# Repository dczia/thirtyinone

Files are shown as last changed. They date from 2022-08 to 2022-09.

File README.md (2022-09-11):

# thirtyinone
defcon 30 30-in-One badge

This Is The Video You Are Looking For (https://www.youtube.com/watch?v=AAD9OO9EeQw "DCZia 30 in 1 Electronic Project Kit Badge Overview")

For those who don't like videos, here is a reasonable ordering of adding components:
* Pins (broken out all at once or a few at a time
* OLED Screen - top left, for pins
* Switches (next to battery, under keycaps hope)
* RGB LED - to the left of the other LEDS
* Speaker bottom right, on top of the spot of tape.  Polarity does not matter
* Battery case (big blank spot, bottom left)
* Key base (top right-should be obvious)
* Transformer (note THIS one is directional-the P side should line up with the P on the board)
* Potentiometer (next to the key base)
* Key Cap

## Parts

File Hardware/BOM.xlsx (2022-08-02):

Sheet: Sheet1
Ref Des | Description | Mfg Part # | Package | Supplier | Supplier Part # | QTY per badge
Transistors
Q101,102 | Transistor NPN 3904 | CMPT3904E TR PBFREE | SOT232 | Mouser | 610-CMPT3904E | 2
Q103 | Transistor PNP 3906 | CMPT3906G TR PBFREE | SOT232 | Mouser | 610-CMPT3906G | 1
Caps
C1 | 2.2uF | 885012107001 | 0805 | Mouser | 710-885012107001 | 1
C2 | 470pF | C0805Y471J9RACTU | 0805 | Mouser | 80-C0805Y471J9R | 1
C3,4,C114 | 10uF | CL10A106MQ8NNND | 0603 | Mouser | 187-CL10A106MQ8NNND | 3
C8 | 1uF | C0603C105K9PACTU | 0603 | Mouser | 80-C0603C105K9P | 1
C9,C10 | 47pF | 06036A470KAT2A | 0603 | Mouser | 581-06036A470KAT2A | 2
C111 | 470uF | 865080153012 |  | Mouser | 710-865080153012 | 1
C112 | 100uF | 865080142007 |  | Mouser | 710-865080142007 | 1
C113 | 22uF | CL21A226MQQNNNE | 0805 | Mouser | 187-CL21A226MQQNNNE | 1
C5-7,115,116 | 0.1uF | 06034C104KAT2A | 0603 | Mouser | 581-06034C104KAT2A | 5
C117 | 0.033uF | GRM1887U0J333JA01D | 0603 | Mouser | 81-GRM1887U0J333JA1D | 1
C118 | 0.01uF | 80-C0603C103K9R | 0603 | Mouser | C0603C103K9RACTU | 1
Diodes
D1,2,3 | Schottky diode single | SS0530_R1_00001 | SOD-123-2 | Mouser | 241-SS0530_R1_00001 | 3
D104 | RGB LED | CLX6F-FKC-CKNNQDGBB7A363 |  | Mouser | 941-CLX6FFKCCKNNQDGB | 1
D3,4 | Schottky diode dual | BAT54S-TP | SOT23 | Mouser | 833-BAT54S-TP | 2
D102,103 | LED Green | 150080GS75000 | 0805 | Mouser | 710-150080GS75000 | 2
Resistors
R1,2 | 27R | ERJ-3GEYJ270V | 0603 | Mouser | 667-ERJ-3GEYJ270V | 2
R103 | 100k | RK73B1JTTD104J | 0603 | Mouser | 660-RK73B1JTTD104J | 1
R104 | 10k | CR0603-JW-103ELF | 0603 | Mouser | 652-CR0603-JW-103ELF | 1
R105 | 5.6k | CR0603-JW-562ELF | 0603 | Mouser | 652-CR0603JW-562ELF | 1
R106 | 1k | ERJ-3GEYJ102V | 0603 | Mouser | 667-ERJ-3GEYJ102V | 1
R107 | 680R | CR0603-JW-681ELF | 0603 | Mouser | 652-CR0603JW-681ELF | 1
R108-110 | 100R | ERJ-3GEYJ101V | 0603 | Mouser | 667-ERJ-3GEYJ101V | 3
R111 | CdS Photo Cell | 161 |  | Mouser | 485-161 | 1
RV101 | 50k Potentiometer | RK09D113000D |  | Mouser | 688-RK09D113000D | 1
Chips
U2 | Microcontroller | ATSAMD21G15A-AU | TQFP-48 | Mouser | 556-ATSAMD21G15A-AU | 1
U1 | LDO vreg | MIC5219-3.6YM5-TR | SOT23 | Mouser | 998-MIC5219-3.6YM5TR | 1
Connectors
J1 | SWD | NO STUFF |  |  |  | 0
J2 | Tag Connect | NO STUFF |  |  |  | 0
J3 | OLED 4 pin header |  |  |  |  | 1
J4 | USB micro | USB3140-30-0170-1-C |  | Mouser | 640-USB31403001701C | 1
J5 | uC interface 14 pin
J105-158,168,169 | 2 pin socket |  |  |  |  | 56
J159-J167 | 3 pin socket |  |  |  |  | 9
J170-175 | 6 pin socket |  |  |  |  | 6
Socket strip | 175 sockets per badge |  | 40 pins | Amazon | https://www.amazon.com/Uxcell-a14081900ux0270-Single-Straight-Header/dp/B012ACSO4Y | 5
Misc
LS101 | Speaker | CMS-151135-078L100 |  | Mouser | 490-CMS151135078L100 | 1
SW1,103 | Switch SPDT | MHSS1104 |  | Mouser | 642-MHSS1104 | 2
SW2 | Push button bootload | PTS526 SK15 SMTR2 LFS |  | Mouser | 611-PTS526SK15SMR2L | 1
SW104 | Cherry MX |  |  |  |  | 1
BT1 | Battery box | 2479 |  | Mouser | 534-2479 | 1
T101 | Transformer | 42TL013-RC |  | Mouser | 42TL013-RC | 1

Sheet: Sheet2
 |  |  | Test? | Sch? | Resistors |  |  |  |  |  |  |  |  |  |  |  |  | Capacitors |  |  |  |  | LEDs |  | Transistor |  |  | Switch
 |  |  |  |  | 100R | 100R | 1K | 1K | 5K | 10K | 10K | 47K | 100k | 50K Pot | Photo | 100pF | 0.01uF | 0.02uF | 0.05uF | 0.1uF | 10uF | 100uF | Single | RGB | 2N3906 PNP | 2N5830 NPN | 2SC NPN | Button | SPST | Speaker | Transformer | Diode | NAND
1 | Light the LED |  |  | Y | x |  |  |  |  |  |  |  |  |  |  |  |  |  |  |  |  |  | x |  |  |  |  | x
2 | LEDs and Resistors |  |  | Y | x |  |  |  |  |  |  |  |  | x |  |  |  |  |  |  |  |  | x |  |  |  |  |  | x
3 | RGB Mixing |  |  | P | x | x |  |  |  |  |  |  |  | x |  |  |  |  |  |  |  |  |  | x |  |  |  |  | x
4 | Storage Tank | 35 in one - 2 |  | Y |  |  |  | x |  |  |  |  |  |  |  |  |  |  |  |  |  | x | x
5 | Diodes | 35 in one - 3 |  | y |  |  |  | x |  |  |  |  |  |  |  |  |  |  |  |  |  |  | x
6 | Resistors in Series/Parallel |  |  |  |  |  | x | x | x | x | x |  |  | x
7 | Temp Sensor | 75 in one - 11 | Y | y |  |  | x |  |  |  |  |  |  | x |  |  |  |  |  |  |  |  |  |  |  | x
8 | Metronome |  | Y | P |  |  |  |  |  | x |  |  |  | x |  |  |  |  |  |  | x |  |  |  | x | x |  |  |  | x
9 | Electronic cat | 150 in one - 8 | y | y |  | x |  |  |  | x |  |  |  | x |  |  | x |  | x |  | x | x |  |  | x |  |  | x | x | x | x
10 | Electronic motorcycle | 150 in one - 9 | y | y |  |  |  |  |  | x |  |  |  |  | x |  |  |  | x | x |  |  |  |  | x |  |  |  |  | x | x
11 | Patrol Car Siren | 150 in one - 11 | y | y |  |  |  |  |  | x |  |  |  |  |  | x | x |  |  |  |  |  |  |  | x |  |  | x
12 | Light Theremin | 150 in one - 16 | y | y |  |  | x |  |  |  |  |  |  |  | x |  |  | x |  | x |  |  |  |  | x |  |  | x |  | x | x
13 | Sunrise/Sunset | 35 in one - 7 | y | y |  |  |  | x |  |  |  |  | x |  |  |  |  |  |  |  |  | x | x |  |  | x
14 | Touch Circuit | 35 in one - 17 | y | y |  |  |  | x | x | x |  |  | x |  |  |  |  |  |  |  |  |  | x |  |  | x | x
15 | The Blinker | 35 in one - 23 | y | y |  |  |  | x | x | x |  |  | x |  |  |  |  |  |  |  | x | x | x |  |  | x | x
16 | Early bird | 150 in one - 91 | y | y |  |  |  |  |  |  |  | x |  | x | x |  | x |  |  | x |  | x |  |  | x |  |  | x |  | x | x
17 | Audio Osc | 150 in one - 144 | y | y | x |  |  |  |  | x | x |  |  | x |  |  |  |  |  | x |  |  |  |  | x | x |  | x |  | x
18 | Grandfather Clock | 500 in one - 41 or 150 in one - 15 | y | y | x |  |  |  |  |  |  |  | x |  |  |  |  | x |  |  |  | x |  |  | x |  |  |  |  | x | x
19 | Pulse Osc | 150 in one - 145 | y | y |  |  |  |  |  |  | x |  |  | x |  |  |  |  | x | x |  |  |  |  | x |  |  | x |  | x | x
20 | Light controlled switch | 150 in one - 72 | y | y |  |  | x | x |  |  |  |  |  | x | x |  |  |  |  |  |  |  | x |  | x
21 | AND with switches | 150 in one - 48 | y | y |  |  |  | x |  |  |  |  |  |  |  |  |  |  |  |  |  |  | x |  |  |  |  | x | x
22 | OR with switches | 150 in one - 49 | y | y |  |  |  | x |  |  |  |  |  |  |  |  |  |  |  |  |  |  | x |  |  |  |  | x | x
23 | NOR with switches | 150 in one - 51 | y | y |  |  |  |  |  |  | x |  |  |  |  |  |  |  |  |  |  |  | x |  | x |  |  | x | x
24 | Code Practice | 150 in one - 105
25 | Pulse Stretcher | 150 in one - 56
26 | RS flip flop | 150 in one - 57
27 | Turn off delay osc | 150 in one - 65
28 | Code RGB
29 | Code frequency counter
30 | Code ADC

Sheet: Sheet3
Part | Qty
Caps
100uF | 1 | p | x
10uF | 1 | p | x
0.05uF | 1 |  | x
0.1uF | 2 |  | x
22uF | 1 |  | x
0.01uF | 1 |  | x
470uF | 1 |  | x
LEDs
LED | 2 |  | x
RGB | 1 |  | x
Speaker | 1 |  | x
2N3904 NPN | 2 |  | x
2N3906 PNP | 1 |  | x
Resistors
100 | 3 |  | x
1k | 1 |  | x
10K | 1 |  | x
5.6K | 1 |  | x
100K | 1 |  | x
680 | 1 |  | x
50K pot | 1 |  | x
Push Switch | 1 |  | x
SPST | 1 |  | x
Transformer | 1 |  | x
CdS cell | 1 |  | x
Total | 28

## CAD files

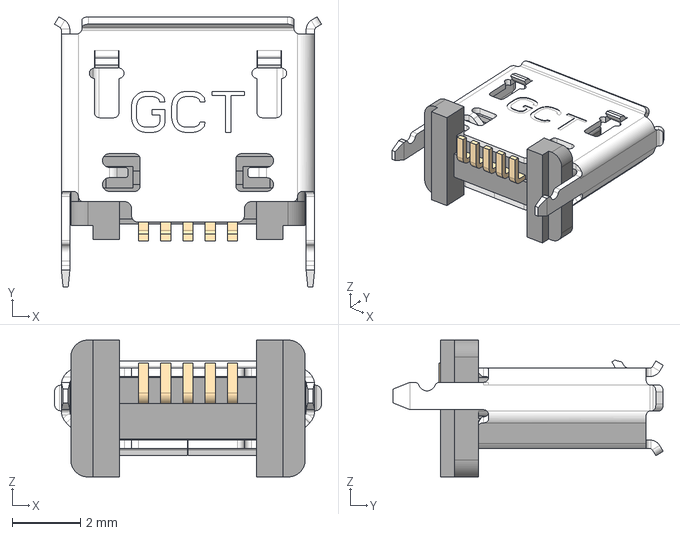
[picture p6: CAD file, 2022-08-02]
Hardware/badge/3d/USB3140-30-0140-1-C.stp
7.80 x 7.90 x 4.00 mm

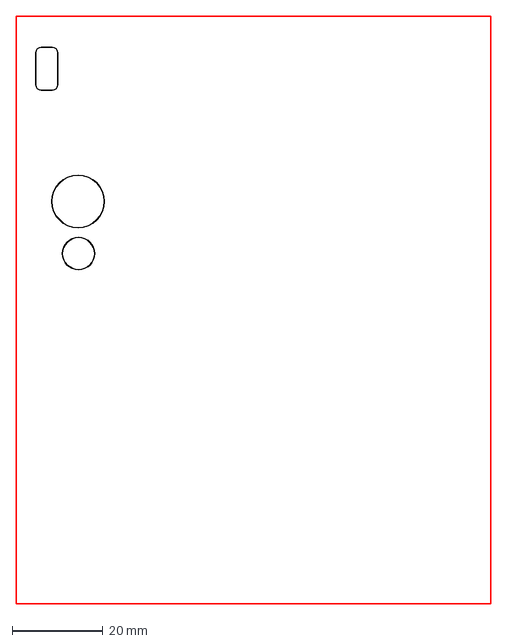
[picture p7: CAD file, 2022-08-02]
Hardware/badge/images/solder-helper.dxf
104.7 x 129.7 mm

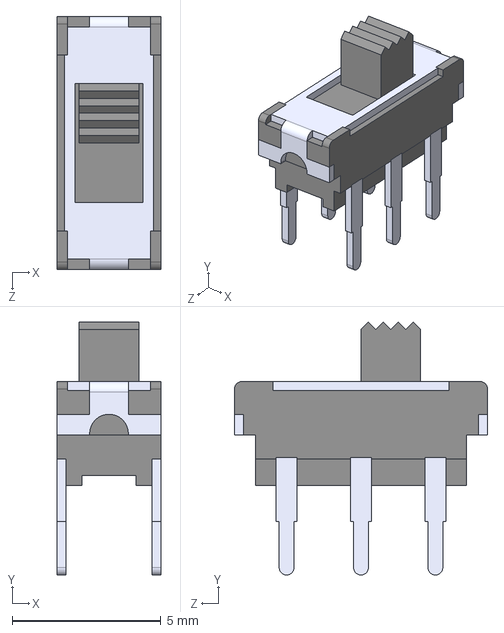
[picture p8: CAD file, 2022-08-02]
Hardware/badge/3d/MHSS1104--3DModel-STEP-56544.STEP
3.50 x 8.50 x 8.50 mm

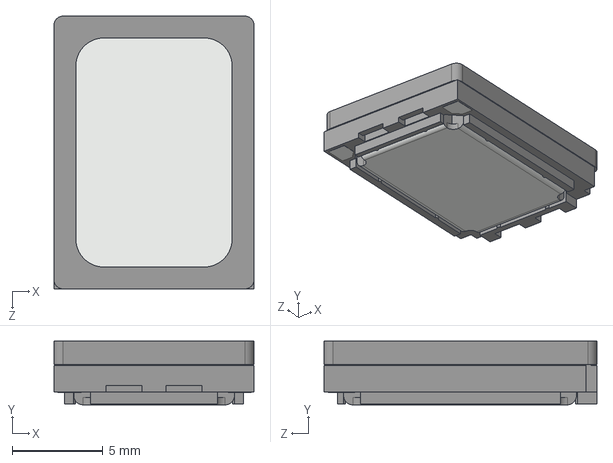
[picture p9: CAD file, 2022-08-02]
Hardware/badge/3d/CUI_DEVICES_CMS-151135-078SP-67.step
11.0 x 3.50 x 15.0 mm

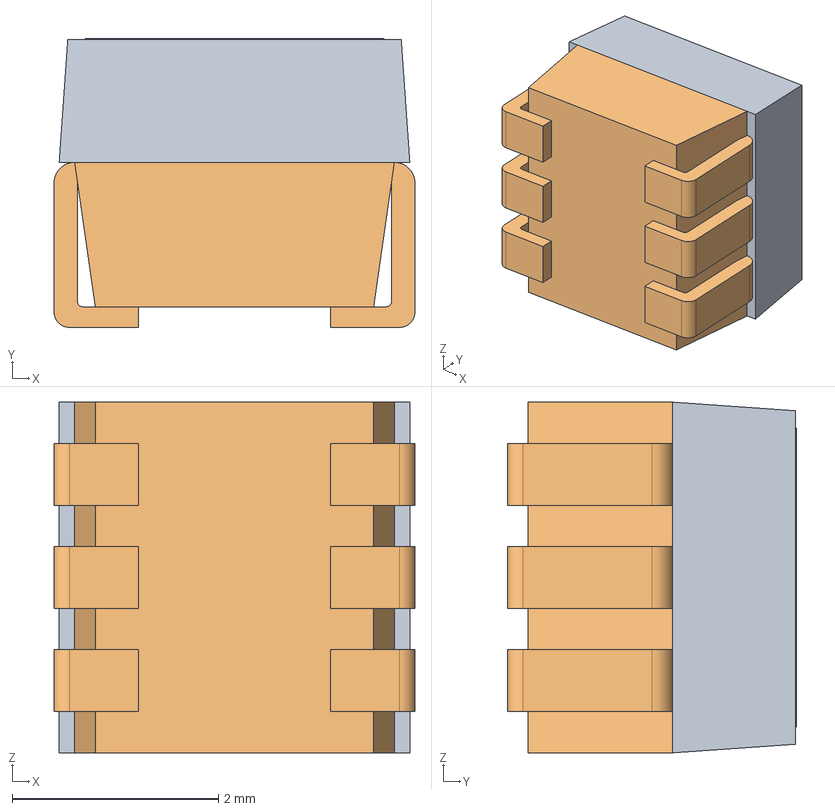
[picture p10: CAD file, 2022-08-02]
Hardware/badge/3d/Cree_PLCC6.stp
3.50 x 2.80 x 3.40 mm
CORPS-DPLACER_COPI0001_1
CORPS-DPLACER_COPI0002_1

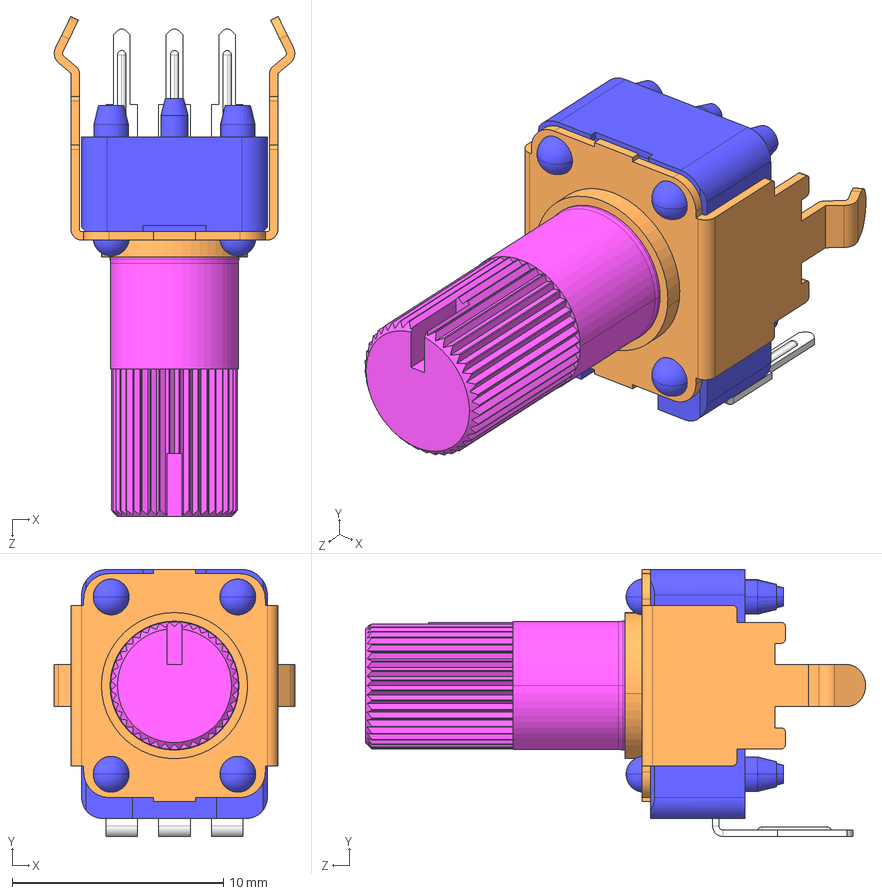
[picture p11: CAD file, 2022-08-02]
Hardware/badge/3d/RK09K1130D62.STEP
11.4 x 12.7 x 23.7 mm

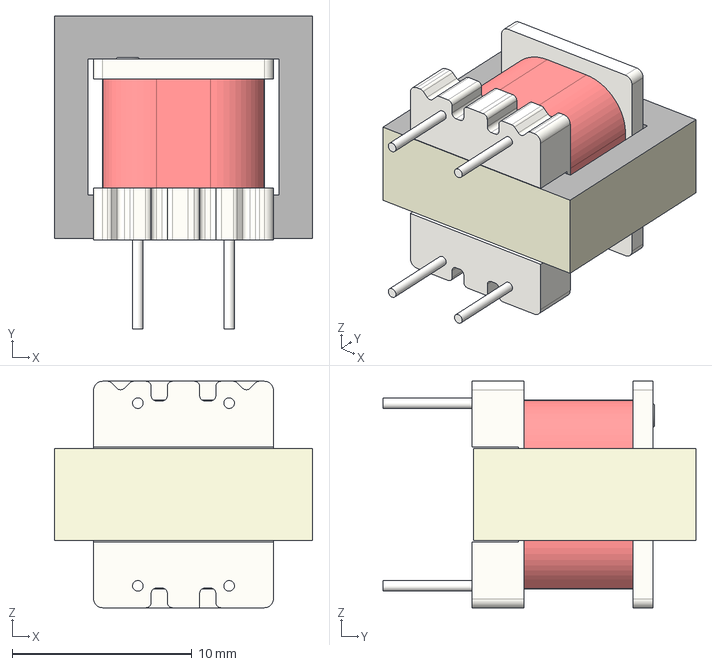
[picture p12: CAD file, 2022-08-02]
Hardware/badge/3d/EE14 Red Audio Transformer v3.step
14.3 x 17.4 x 12.6 mm

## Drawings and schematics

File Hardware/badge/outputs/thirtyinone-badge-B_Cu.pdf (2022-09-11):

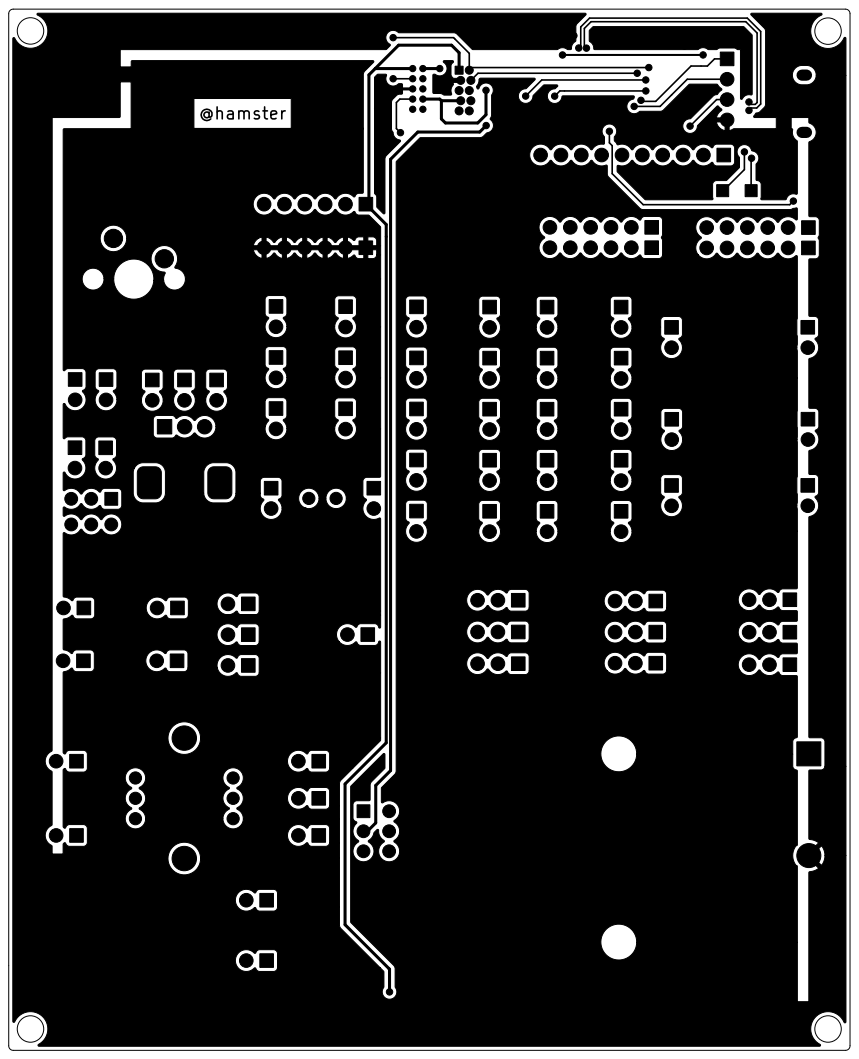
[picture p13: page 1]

File: thirtyinone-badge.kicad_pcb Sheet: DCZia

Id: 1/1 Title: 30-in-One

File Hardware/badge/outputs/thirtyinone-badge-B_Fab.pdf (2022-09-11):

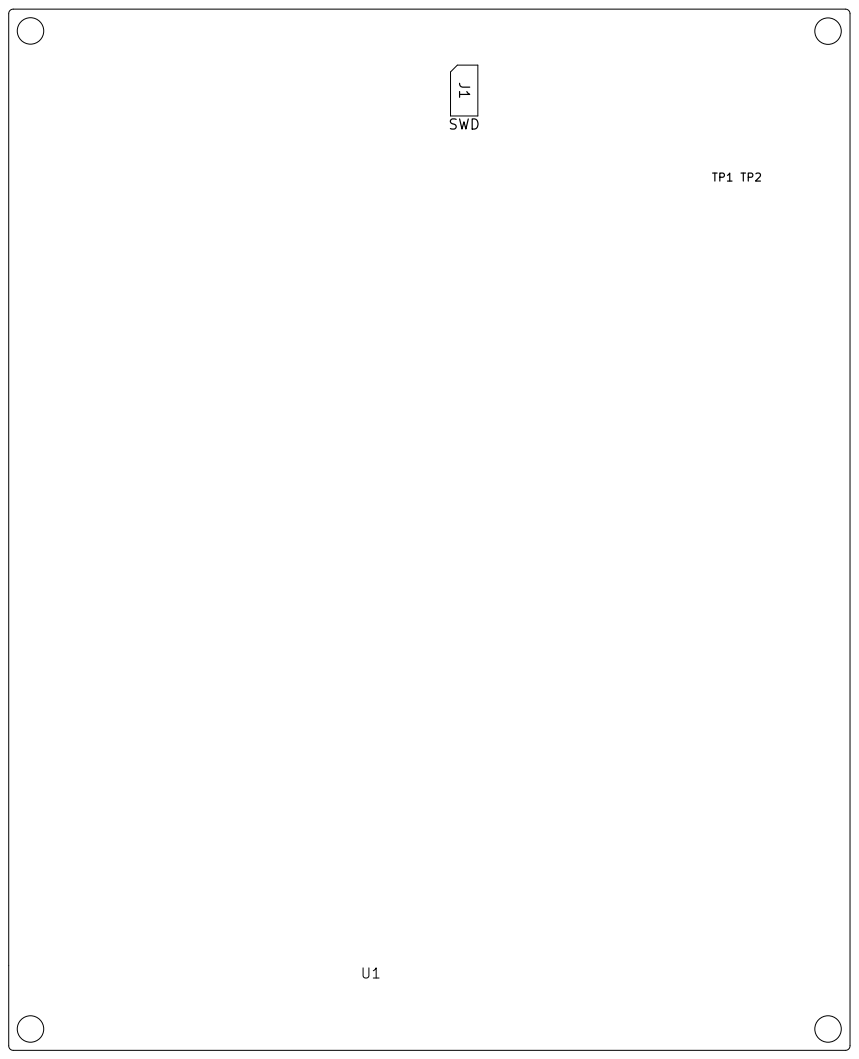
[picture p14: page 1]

File: thirtyinone-badge.kicad_pcb Sheet: DCZia

Id: 1/1 Title: 30-in-One

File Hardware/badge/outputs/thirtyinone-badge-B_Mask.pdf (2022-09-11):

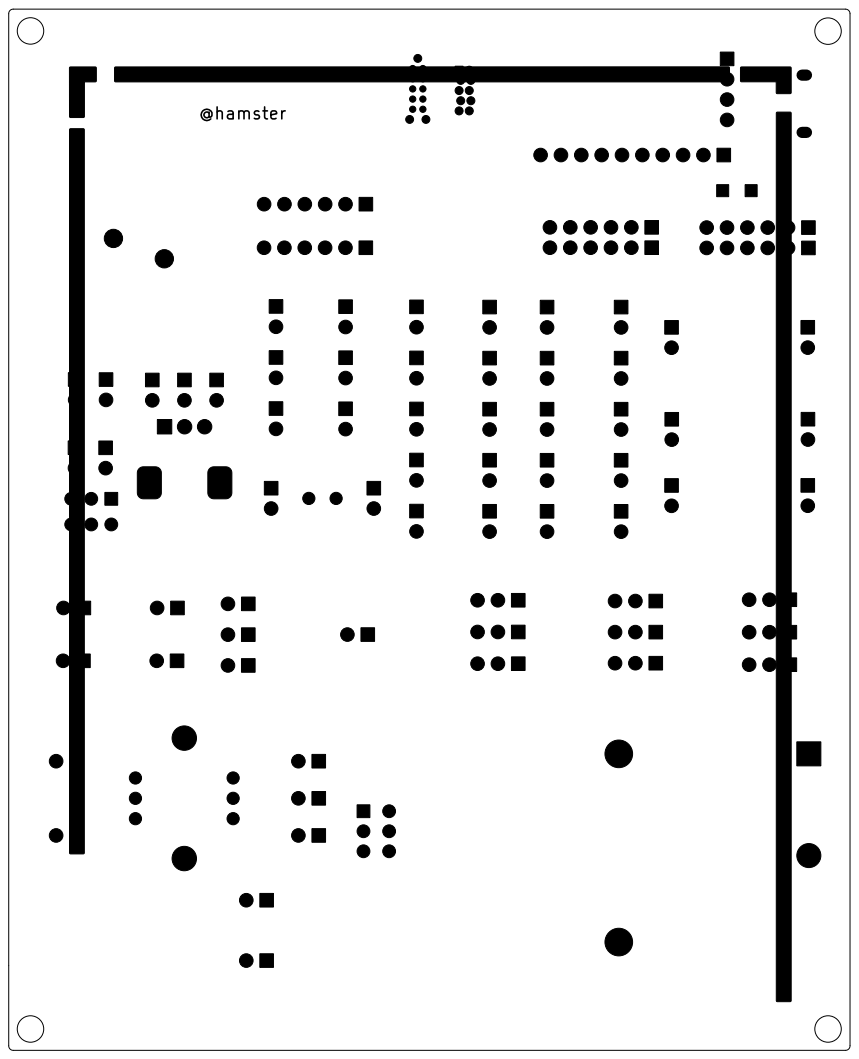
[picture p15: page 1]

File: thirtyinone-badge.kicad_pcb Sheet: DCZia

Id: 1/1 Title: 30-in-One

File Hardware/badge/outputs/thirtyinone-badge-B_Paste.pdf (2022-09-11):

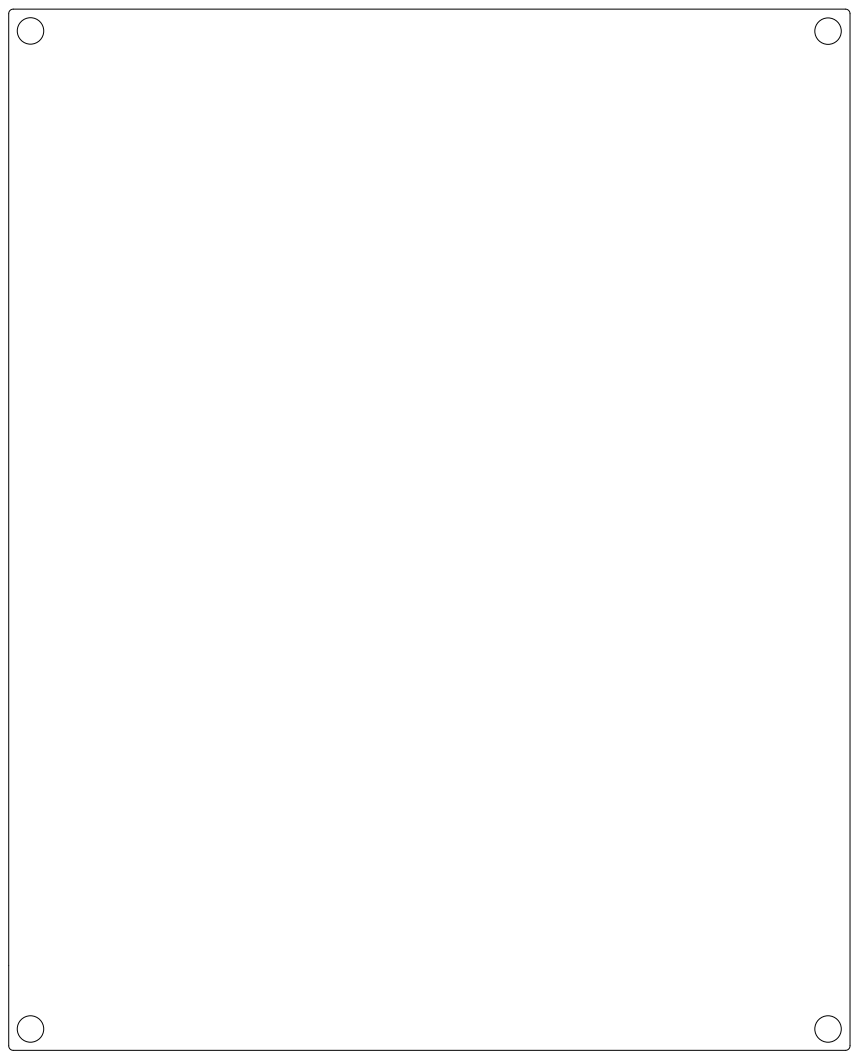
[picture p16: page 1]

defcon 30
File: thirtyinone-badge.kicad_pcb Sheet: DCZia

Id: 1/1 Title: 30-in-One

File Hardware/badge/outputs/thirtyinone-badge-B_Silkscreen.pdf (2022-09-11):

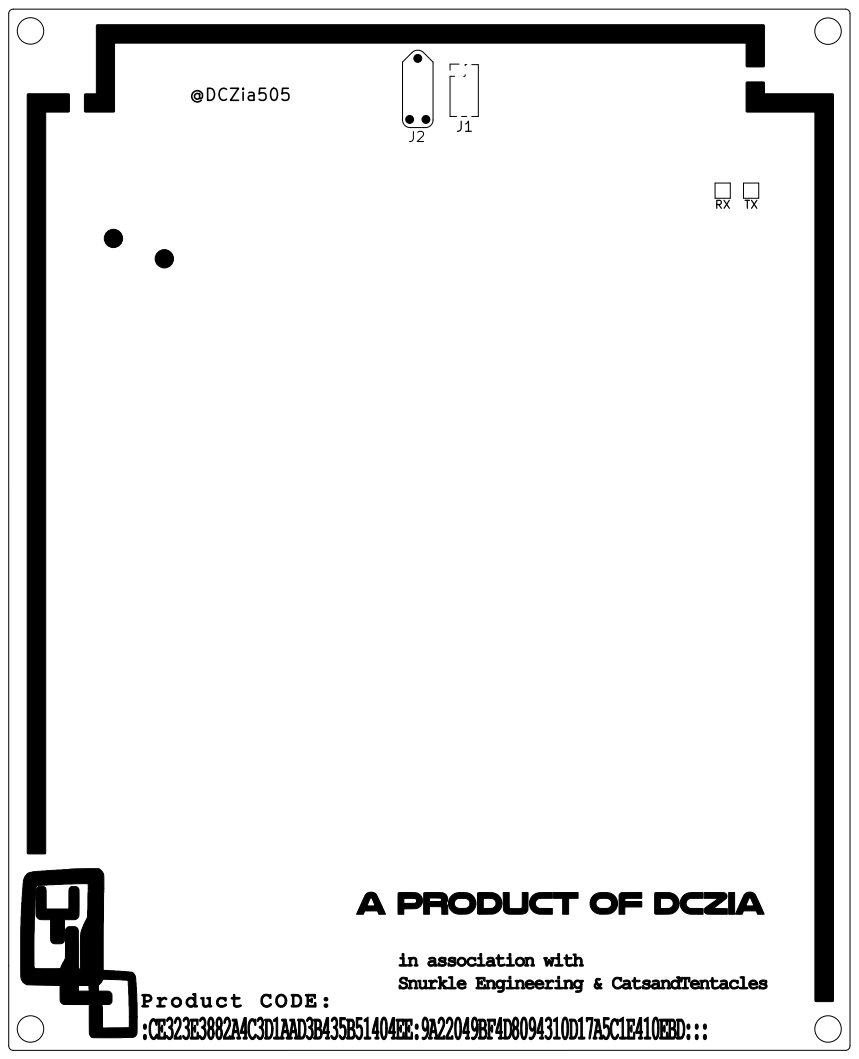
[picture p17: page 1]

File: thirtyinone-badge.kicad_pcb Sheet: DCZia

Id: 1/1 Title: 30-in-One

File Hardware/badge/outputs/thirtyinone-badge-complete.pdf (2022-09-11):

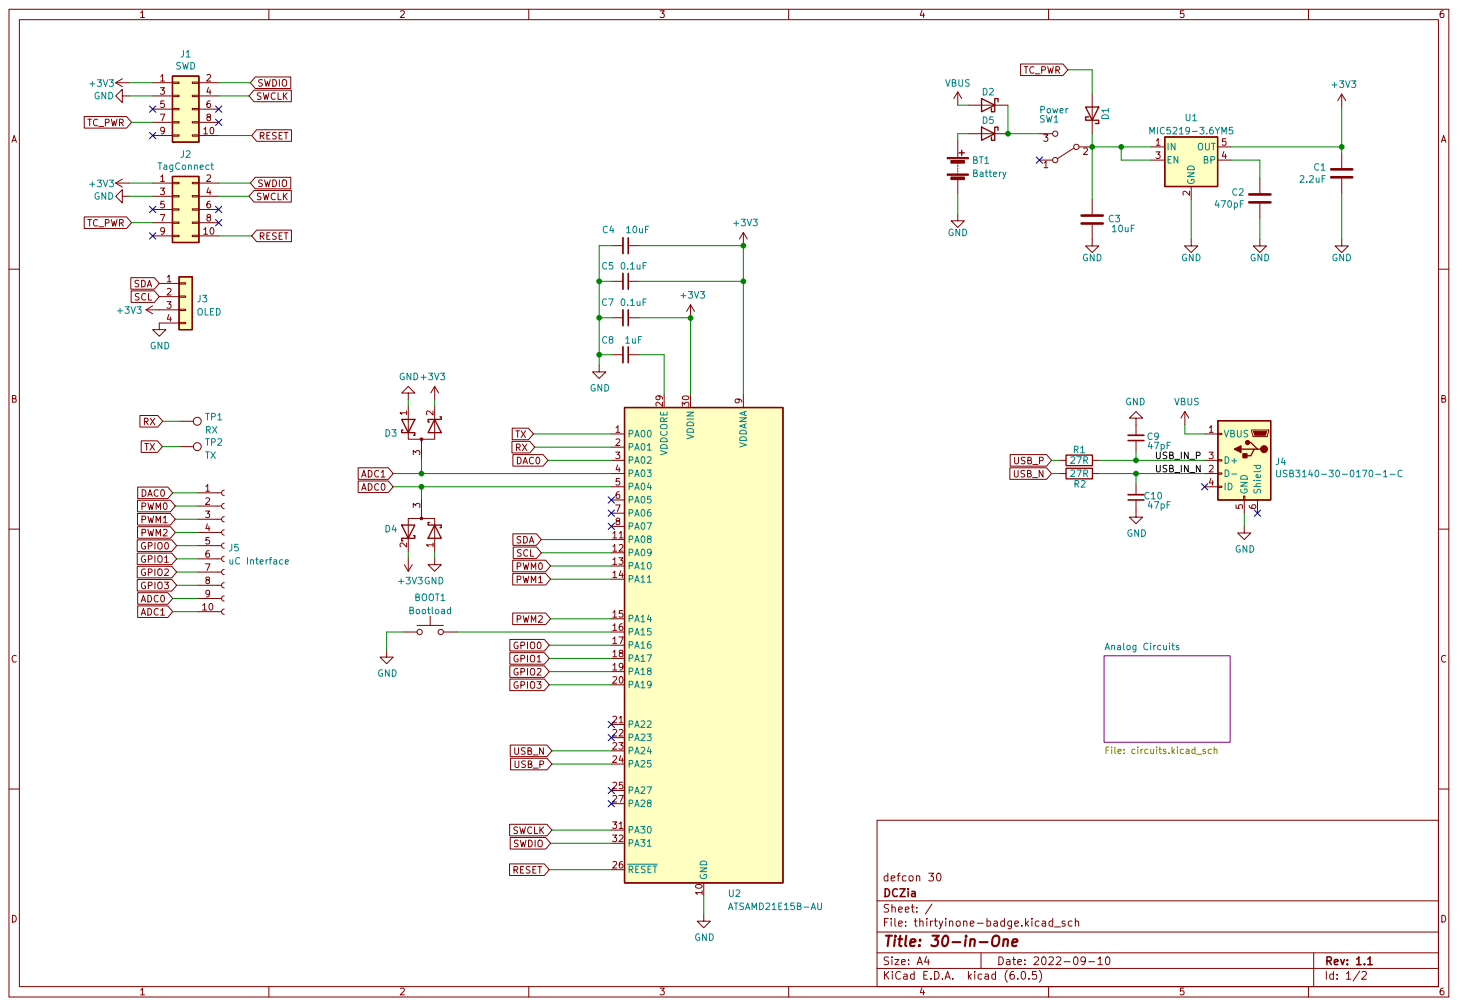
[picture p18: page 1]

File: thirtyinone-badge.kicad_sch Sheet: / DCZia

Id: 1/2 Title: 30-in-One

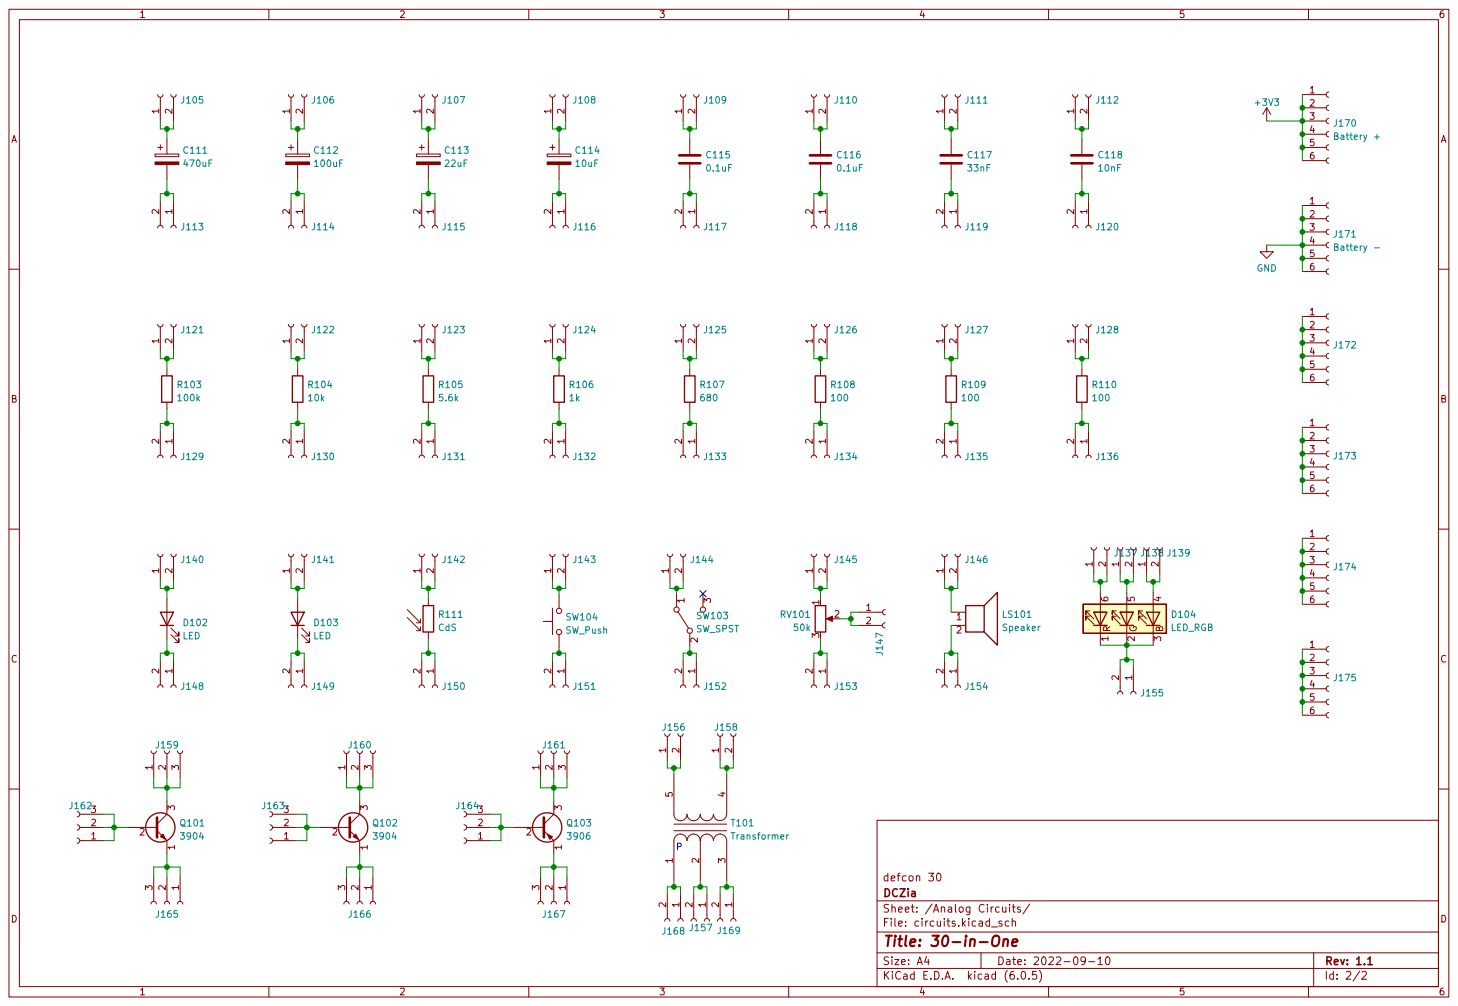
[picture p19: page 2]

defcon 30
Sheet: /Analog Circuits/ DCZia

File: circuits.kicad_sch
Id: 2/2 Title: 30-in-One


File: thirtyinone-badge.kicad_pcb Sheet: DCZia

Id: 1/1 Title: 30-in-One


File: thirtyinone-badge.kicad_pcb Sheet: DCZia

Id: 1/1 Title: 30-in-One


File: thirtyinone-badge.kicad_pcb Sheet: DCZia

Id: 1/1 Title: 30-in-One


defcon 30
File: thirtyinone-badge.kicad_pcb Sheet: DCZia

Id: 1/1 Title: 30-in-One


File: thirtyinone-badge.kicad_pcb Sheet: DCZia

Id: 1/1 Title: 30-in-One

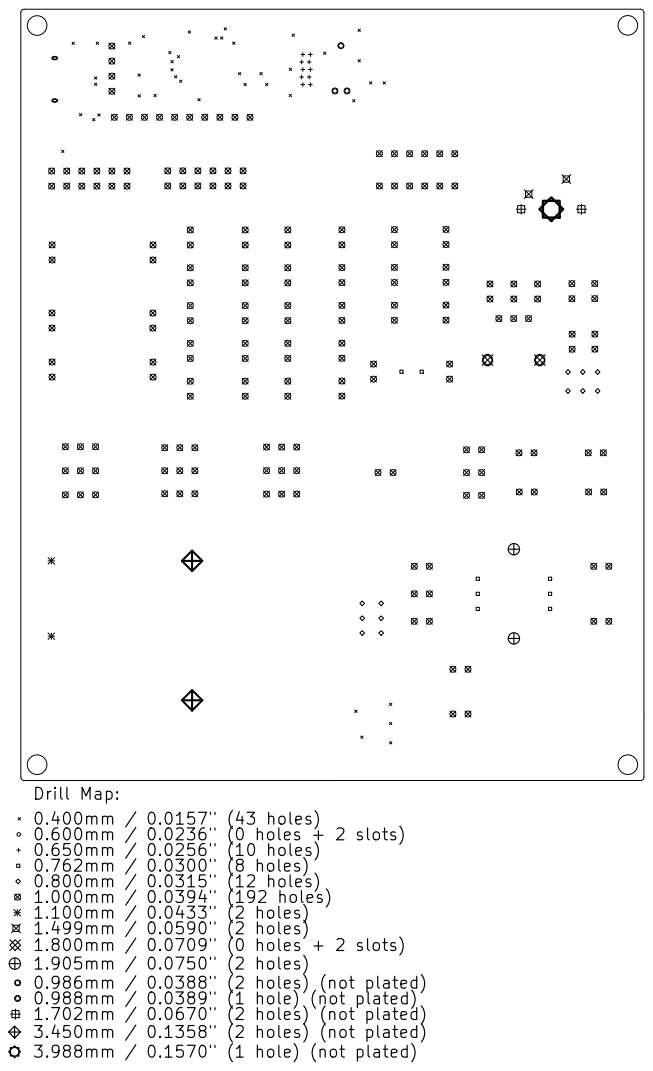
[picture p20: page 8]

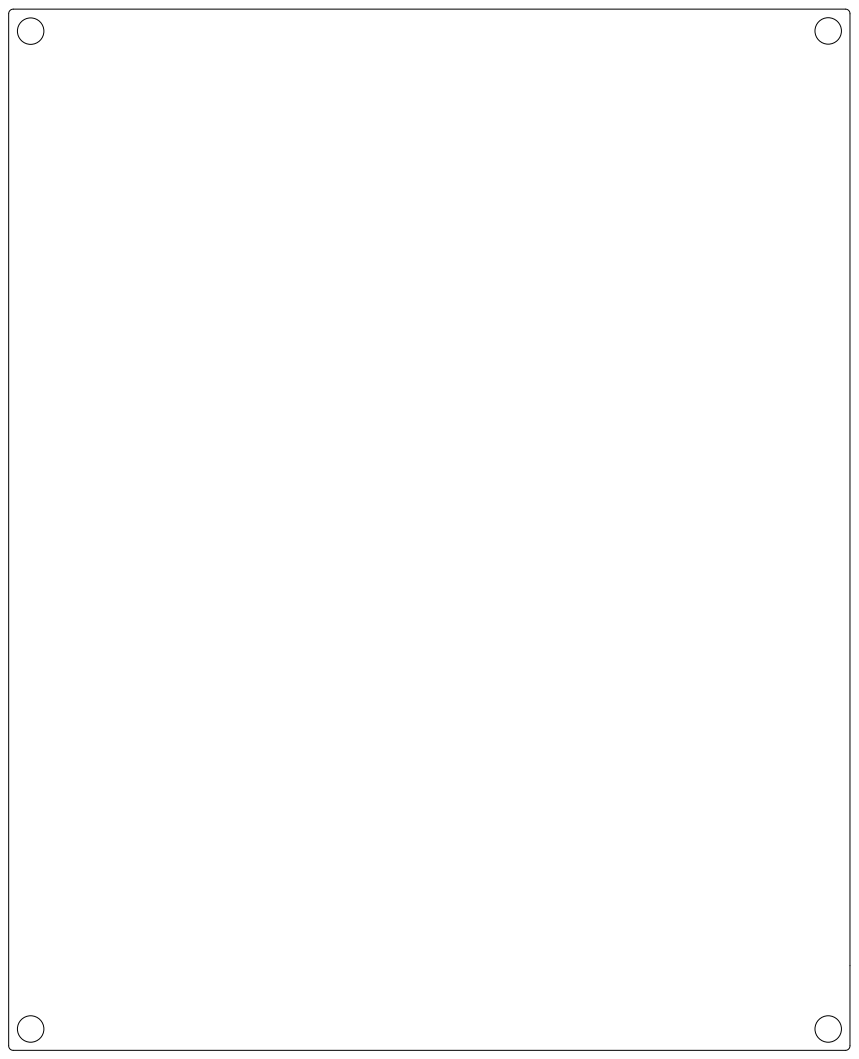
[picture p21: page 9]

defcon 30
File: thirtyinone-badge.kicad_pcb Sheet: DCZia

Id: 1/1 Title: 30-in-One

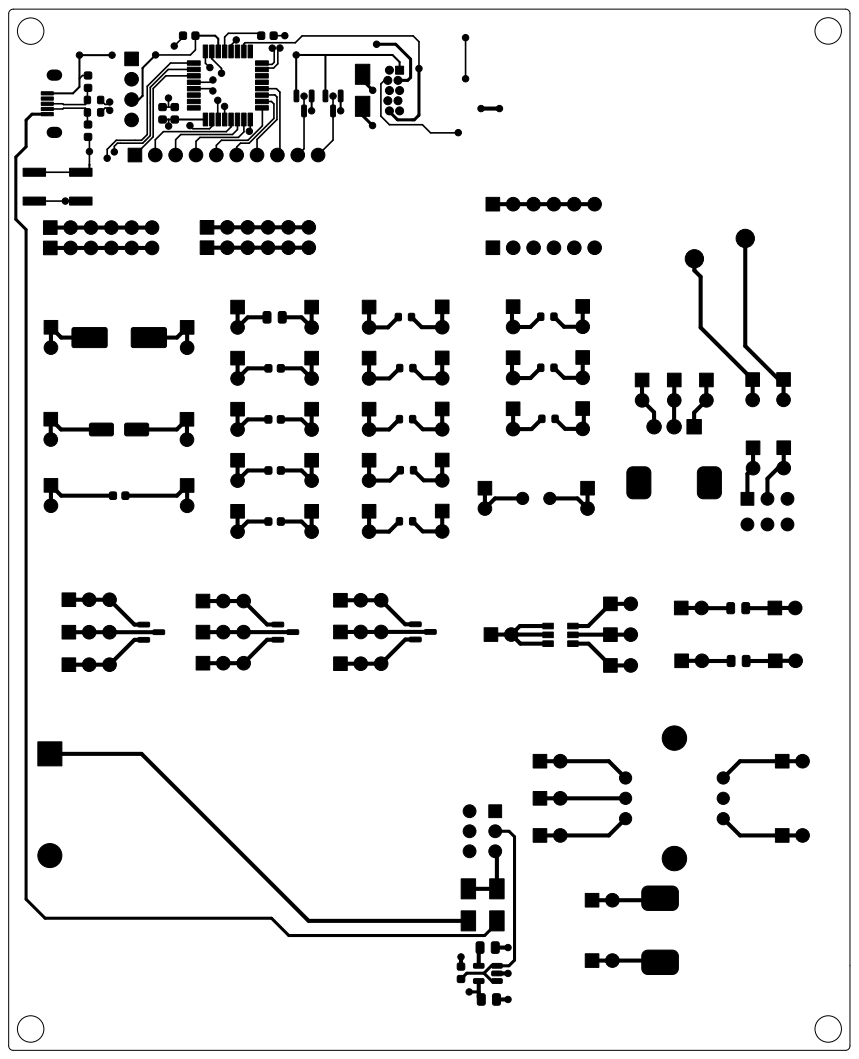
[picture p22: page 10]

defcon 30
File: thirtyinone-badge.kicad_pcb Sheet: DCZia

Id: 1/1 Title: 30-in-One

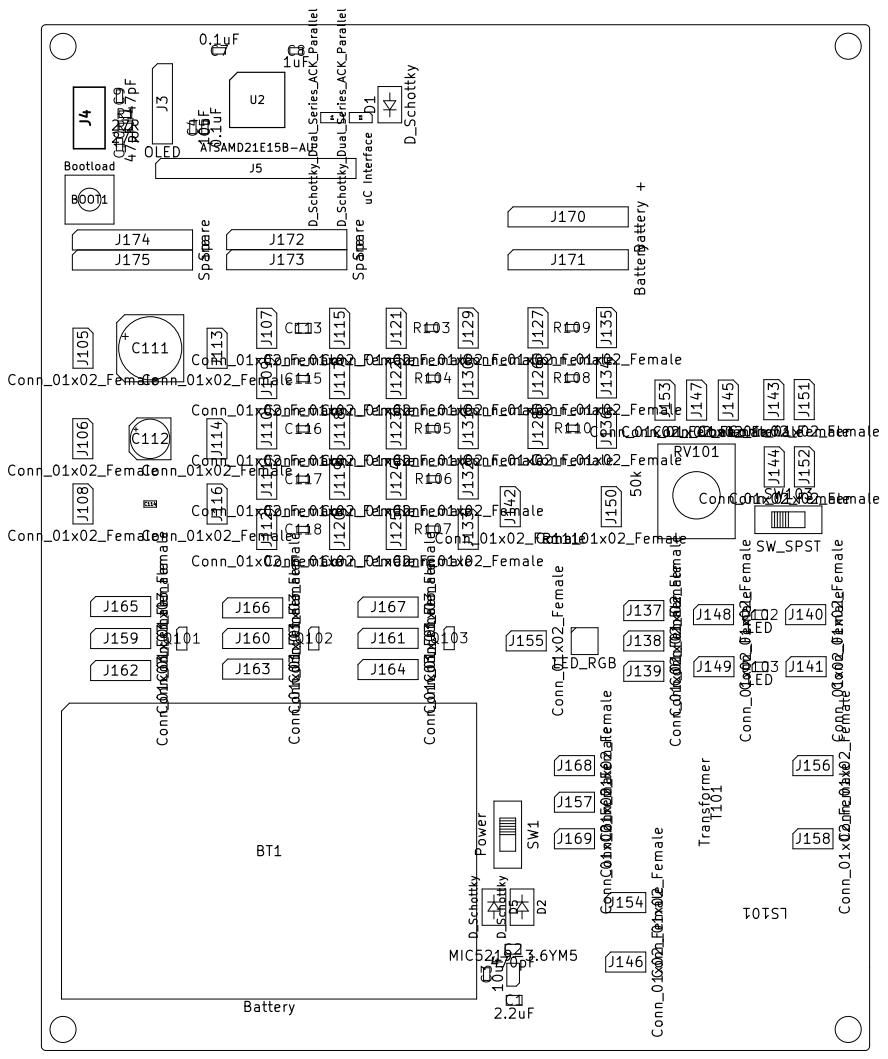
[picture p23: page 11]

File: thirtyinone-badge.kicad_pcb Sheet: DCZia

Id: 1/1 Title: 30-in-One

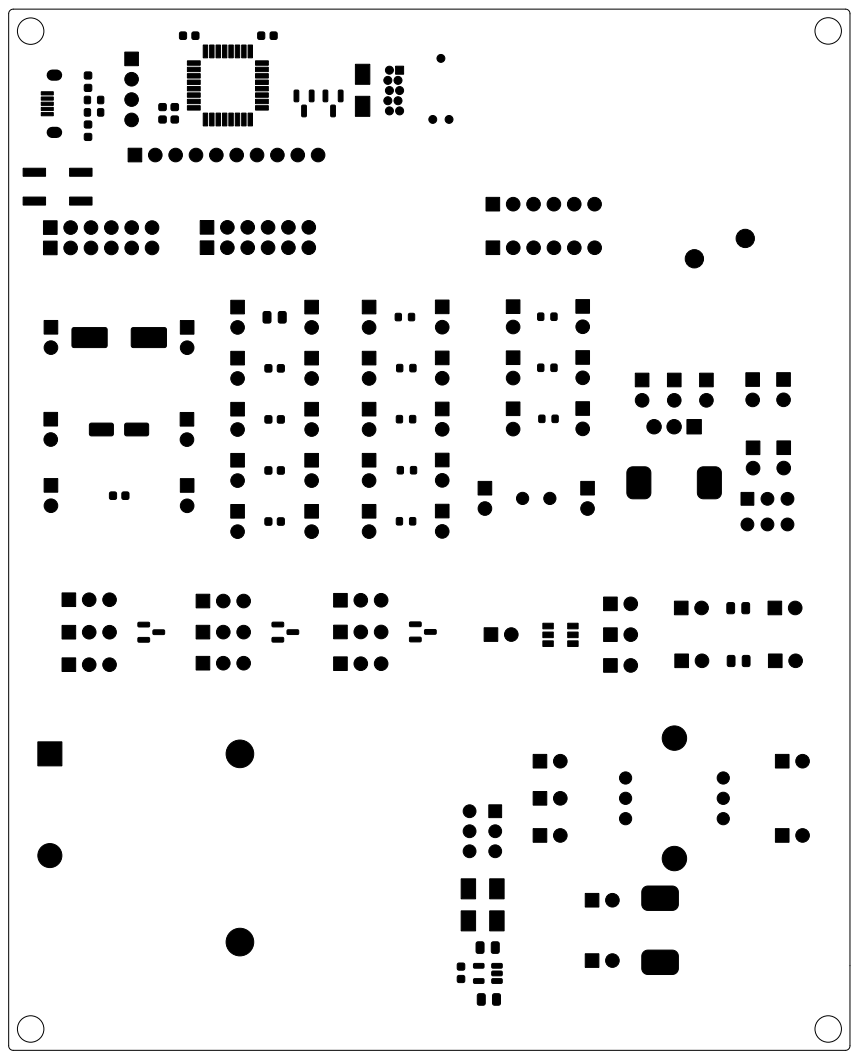
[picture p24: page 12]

defcon 30
File: thirtyinone-badge.kicad_pcb Sheet: DCZia

Id: 1/1 Title: 30-in-One


defcon 30
File: thirtyinone-badge.kicad_pcb Sheet: DCZia

Id: 1/1 Title: 30-in-One


File: thirtyinone-badge.kicad_pcb Sheet: DCZia

Id: 1/1 Title: 30-in-One

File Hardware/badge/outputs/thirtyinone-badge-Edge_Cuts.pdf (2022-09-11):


defcon 30
File: thirtyinone-badge.kicad_pcb Sheet: DCZia

Id: 1/1 Title: 30-in-One

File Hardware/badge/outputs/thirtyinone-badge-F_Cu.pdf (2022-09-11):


defcon 30
File: thirtyinone-badge.kicad_pcb Sheet: DCZia

Id: 1/1 Title: 30-in-One

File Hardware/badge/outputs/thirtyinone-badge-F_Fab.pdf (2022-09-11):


File: thirtyinone-badge.kicad_pcb Sheet: DCZia

Id: 1/1 Title: 30-in-One

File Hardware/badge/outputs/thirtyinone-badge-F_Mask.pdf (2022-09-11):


defcon 30
File: thirtyinone-badge.kicad_pcb Sheet: DCZia

Id: 1/1 Title: 30-in-One

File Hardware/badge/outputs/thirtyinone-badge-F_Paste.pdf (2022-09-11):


defcon 30
File: thirtyinone-badge.kicad_pcb Sheet: DCZia

Id: 1/1 Title: 30-in-One

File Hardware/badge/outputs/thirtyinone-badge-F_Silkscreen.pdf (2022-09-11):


File: thirtyinone-badge.kicad_pcb Sheet: DCZia

Id: 1/1 Title: 30-in-One

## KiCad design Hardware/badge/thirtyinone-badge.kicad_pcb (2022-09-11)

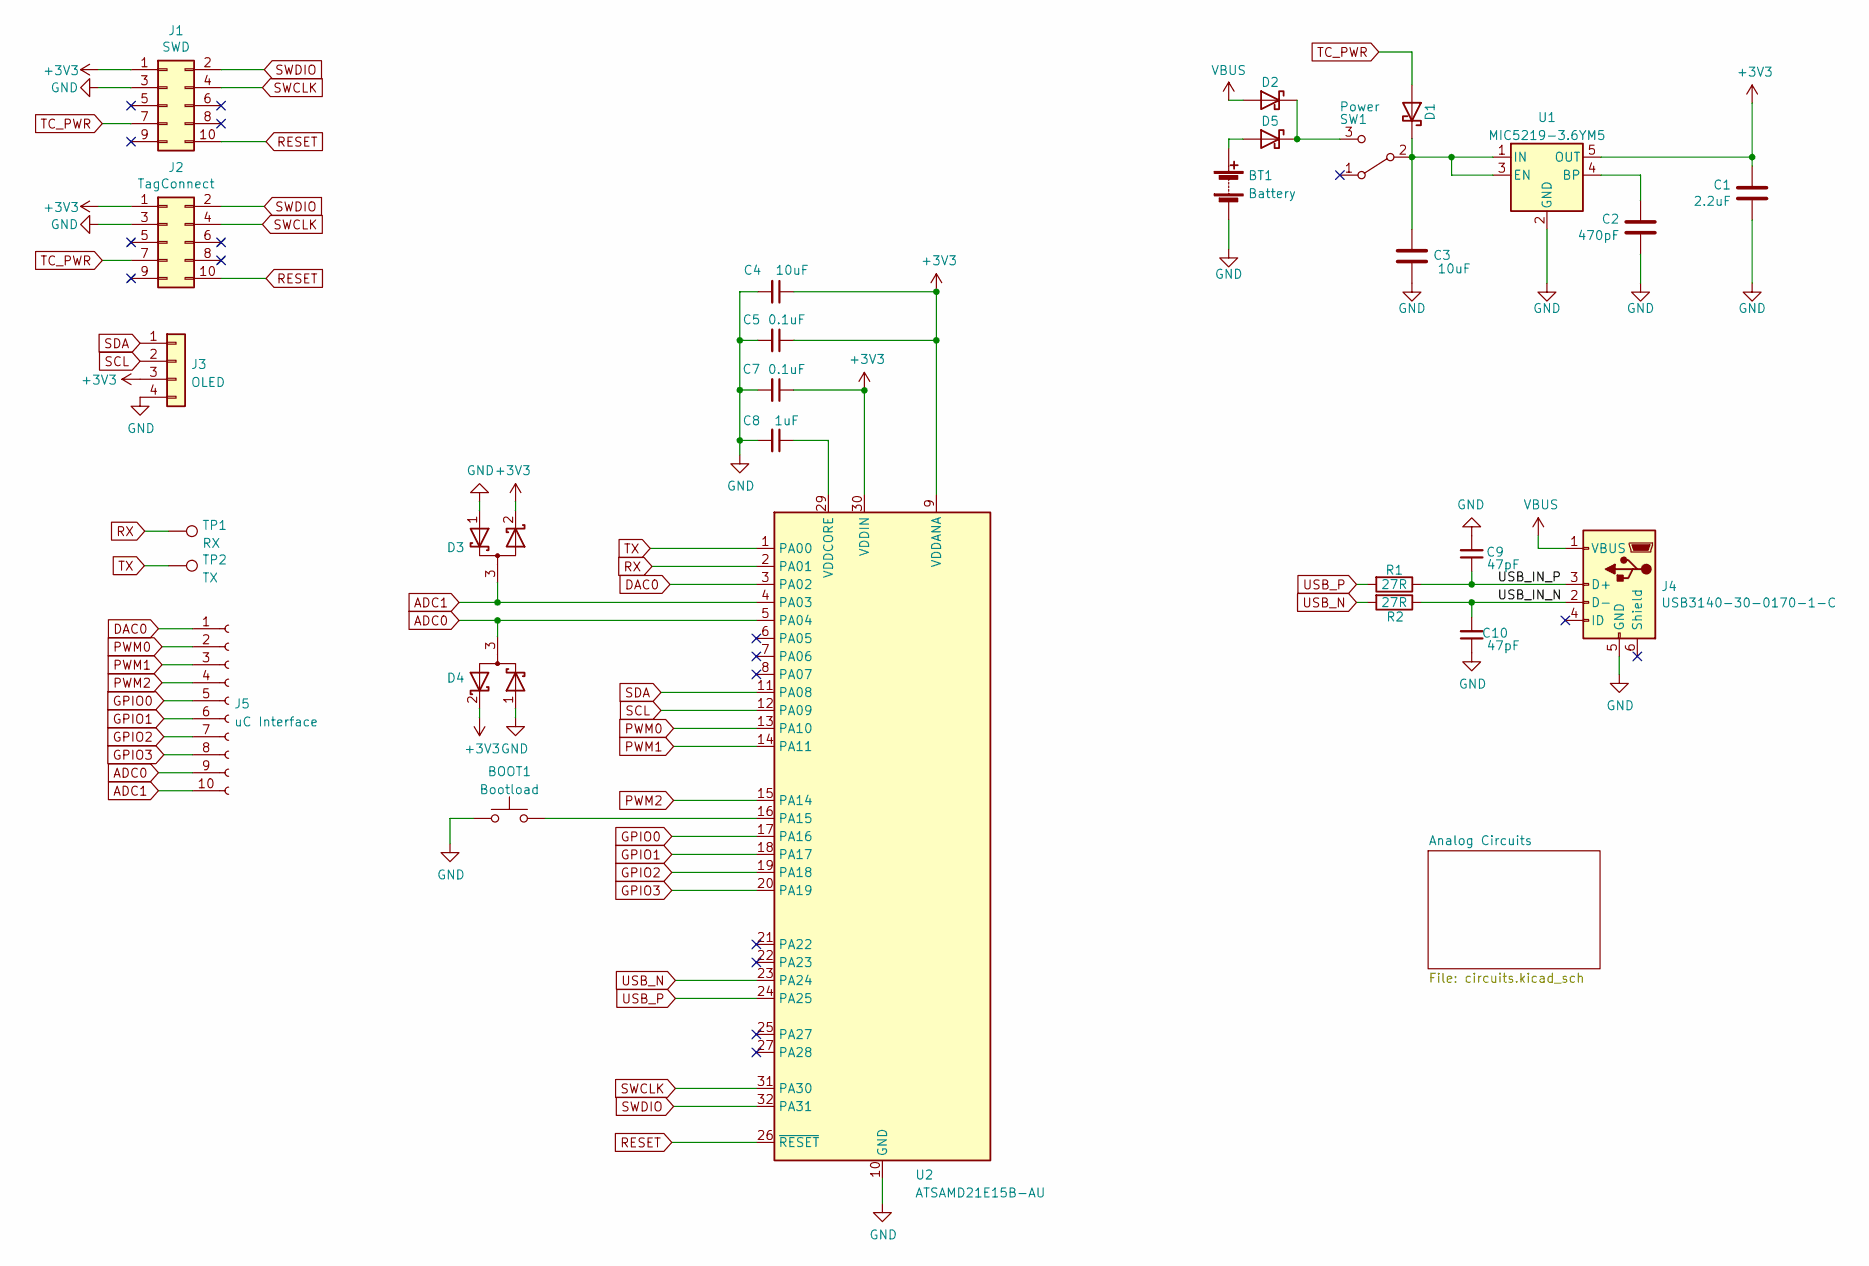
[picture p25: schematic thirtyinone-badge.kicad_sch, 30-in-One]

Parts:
BOOT1: Bootload; SW_Push_1P1T_NO_CK_PTS526
BT1: Battery; BatteryHolder_Keystone_2479_3xAAA
C1: 2.2uF; C_0805_2012Metric
C2: 470pF; C_0805_2012Metric
C3, C4: 10uF; C_0603_1608Metric
C5, C7: 0.1uF; C_0603_1608Metric
C8: 1uF; C_0603_1608Metric
C9, C10: 47pF; C_0603_1608Metric
D1, D2, D5: D_Schottky; D_SMA
D3, D4: D_Schottky_Dual_Series_ACK_Parallel; SOT-23
J1: SWD; PinHeader_2x05_P1.27mm_Vertical_Sneaky
J2: TagConnect; TC2050-NL_SMALL
J3: OLED; PinHeader_1x04_P2.54mm_Vertical
J4: USB3140-30-0170-1-C; USB31403001701C
J5: uC Interface; PinSocket_1x10_P2.54mm_Vertical
R1, R2: 27R; R_0603_1608Metric
SW1: Power; SW_E-Switch_EG1271_DPDT
TP1: RX; TestPoint_Pad_1.5x1.5mm
TP2: TX; TestPoint_Pad_1.5x1.5mm
U1: MIC5219-3.6YM5; SOT-23-5
U2: ATSAMD21E15B-AU; TQFP-32_7x7mm_P0.8mm

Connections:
+3V3: C1.1, C4.1, C5.1, C7.1, D3.2 (K), D4.2 (K), J1.1, J2.1, J3.3, U1.5 (OUT), U2.9 (VDDANA), U2.30 (VDDIN); also elsewhere on the board
/USB_IN_N: C10.2, J4.2 (D-), R2.1
/USB_IN_P: C9.1, J4.3 (D+), R1.1
ADC0: D4.3 (A), J5.9, U2.5 (PA04)
ADC1: D3.3 (A), J5.10, U2.4 (PA03)
DAC0: J5.1, U2.3 (PA02)
GND: BOOT1.1, BT1.2 (-), C1.2, C2.2, C3.2, C4.2, C5.2, C7.2, C8.2, C9.2, C10.1, D3.1 (K), D4.1 (K), J1.3, J2.3, J3.4, J4.5 (GND), U1.2 (GND), U2.10 (GND), U2.28 (GND); also elsewhere on the board
GPIO0: J5.5, U2.17 (PA16)
GPIO1: J5.6, U2.18 (PA17)
GPIO2: J5.7, U2.19 (PA18)
GPIO3: J5.8, U2.20 (PA19)
unnamed: BOOT1.2, U2.16 (PA15)
unnamed: BT1.1 (+), D5.2 (A)
unnamed: C2.1, U1.4 (BP)
unnamed: C3.1, D1.1 (K), SW1.2 (B), U1.1 (IN), U1.3 (EN)
unnamed: C8.1, U2.29 (VDDCORE)
unnamed: D2.1 (K), D5.1 (K), SW1.3 (C)
PWM0: J5.2, U2.13 (PA10)
PWM1: J5.3, U2.14 (PA11)
PWM2: J5.4, U2.15 (PA14)
RESET: J1.10, J2.10, U2.26 (~RESET)
RX: TP1.1, U2.2 (PA01)
SCL: J3.2, U2.12 (PA09)
SDA: J3.1, U2.11 (PA08)
SWCLK: J1.4, J2.4, U2.31 (PA30)
SWDIO: J1.2, J2.2, U2.32 (PA31)
TC_PWR: D1.2 (A), J1.7, J2.7
TX: TP2.1, U2.1 (PA00)
USB_N: R2.2, U2.23 (PA24)
USB_P: R1.2, U2.24 (PA25)
VBUS: D2.2 (A), J4.1 (VBUS)

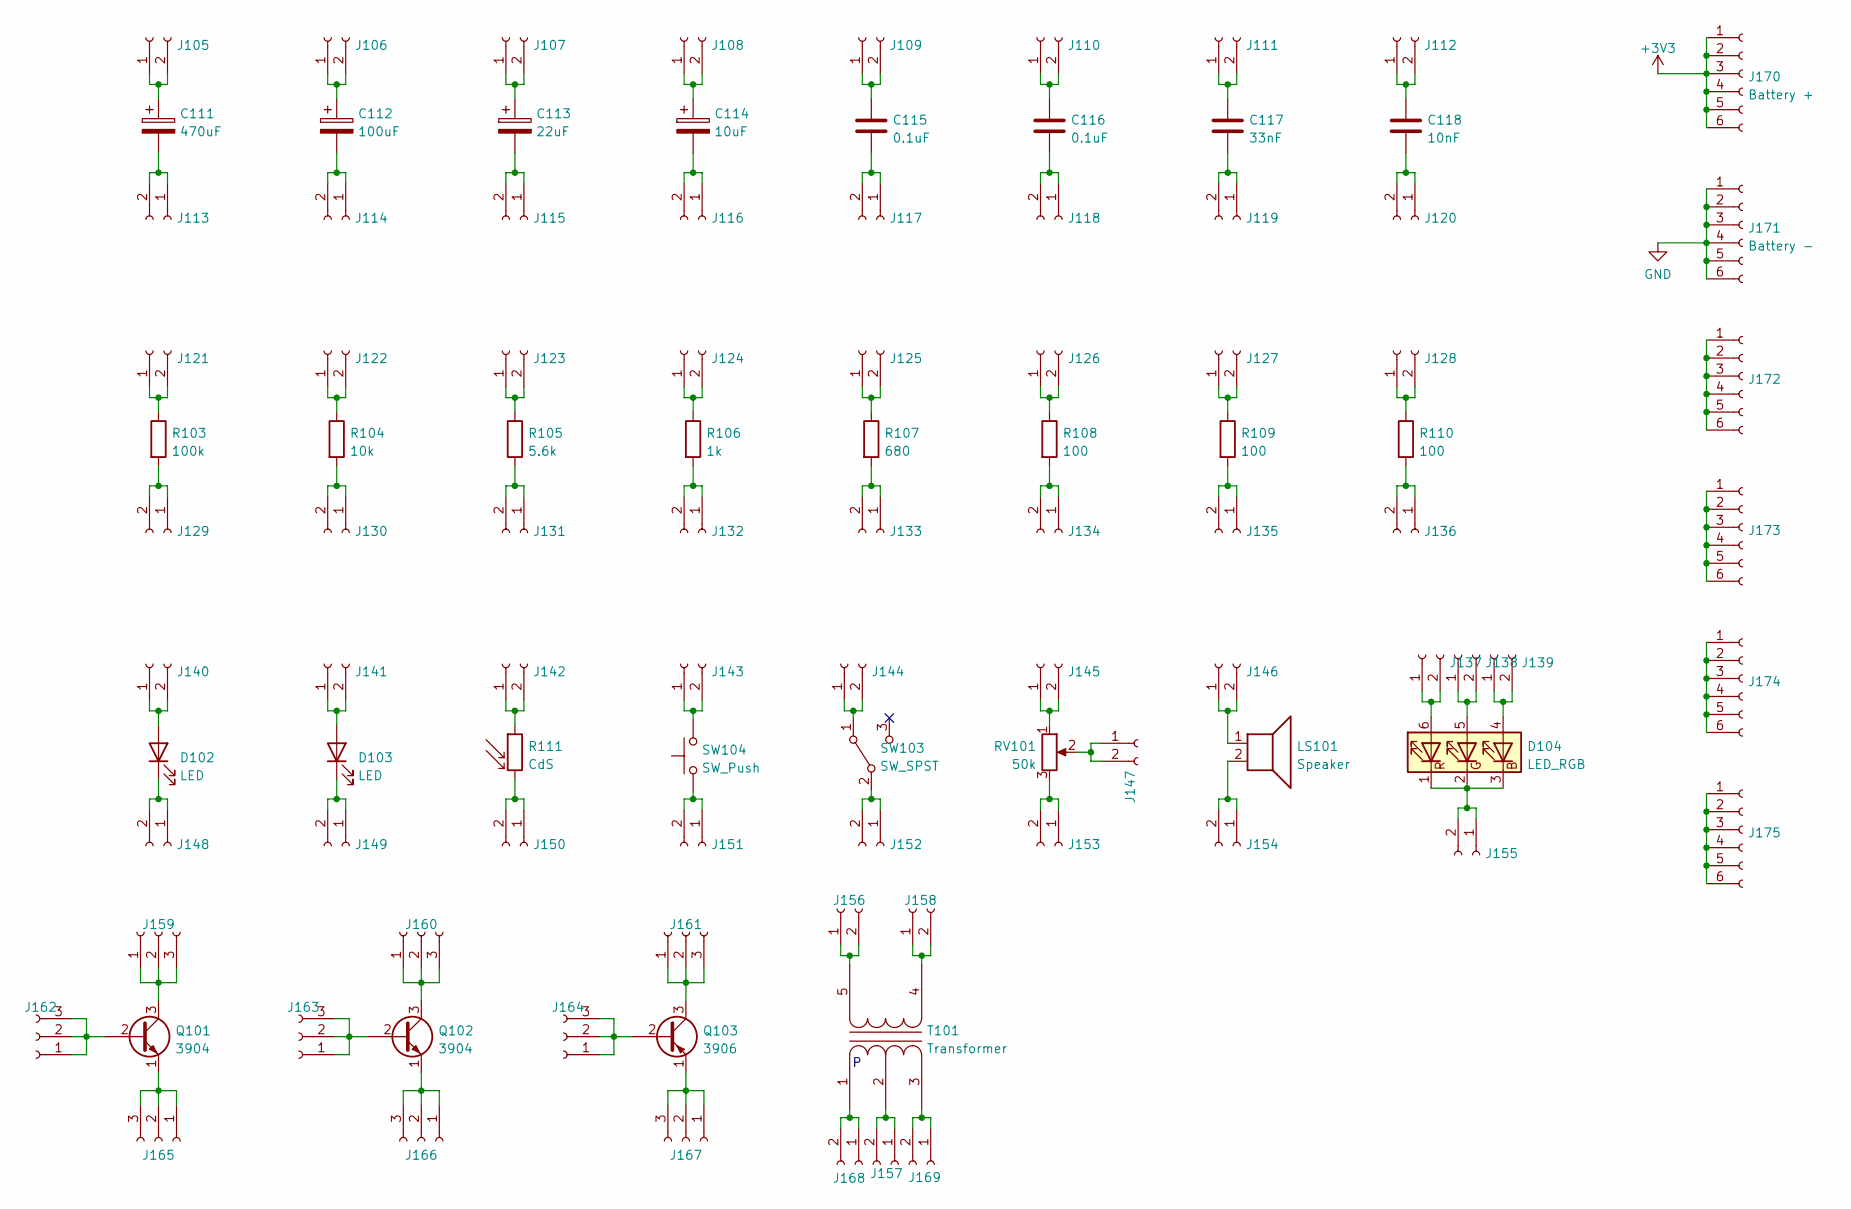
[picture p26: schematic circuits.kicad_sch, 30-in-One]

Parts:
C111: 470uF; CP_Elec_8x10.5
C112: 100uF; CP_Elec_5x5.4
C113: 22uF; C_0805_2012Metric
C114: 10uF; C_0603_1608Metric
C115, C116: 0.1uF; C_0603_1608Metric
C117: 33nF; C_0603_1608Metric
C118: 10nF; C_0603_1608Metric
D102, D103: LED; LED_0805_2012Metric
D104: LED_RGB; LED_RGB_PLCC-6
J105, J106, J107, J108, J109, J110, J111, J112, J113, J114, J115, J116, J117, J118, J119, J120, J121, J122, J123, J124, J125, J126, J127, J128, J129, J130, J131, J132, J133, J134, J135, J136, J137, J138, J139, J140, J141, J142, J143, J144, J145, J146, J147, J148, J149, J150, J151, J152, J153, J154, J155, J156, J157, J158, J168, J169: Conn_01x02_Female; PinSocket_1x02_P2.54mm_Vertical
J159, J160, J161, J162, J163, J164, J165, J166, J167: Conn_01x03_Female; PinSocket_1x03_P2.54mm_Vertical
J170: Battery +; PinSocket_1x06_P2.54mm_Vertical
J171: Battery -; PinSocket_1x06_P2.54mm_Vertical
J172, J173, J174, J175: Spare; PinSocket_1x06_P2.54mm_Vertical
LS101: Speaker
Q101, Q102: 3904; SOT-23
Q103: 3906; SOT-23
R103: 100k; R_0603_1608Metric
R104: 10k; R_0603_1608Metric
R105: 5.6k; R_0603_1608Metric
R106: 1k; R_0603_1608Metric
R107: 680; R_0603_1608Metric
R108, R109, R110: 100; R_0603_1608Metric
R111: CdS; CdS Cell
RV101: 50k; Potentiometer_Alps_RK09K_Single_Vertical
SW103: SW_SPST; SW_E-Switch_EG1271_DPDT
SW104: SW_Push; CHERRY_SMDLED_100H
T101: Transformer; 42TL Transformer

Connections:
+3V3: J170.1, J170.2, J170.3, J170.4, J170.5, J170.6; also elsewhere on the board
GND: J171.1, J171.2, J171.3, J171.4, J171.5, J171.6; also elsewhere on the board
unnamed: C111.1, J105.1, J105.2
unnamed: C111.2, J113.1, J113.2
unnamed: C112.1, J106.1, J106.2
unnamed: C112.2, J114.1, J114.2
unnamed: C113.1, J107.1, J107.2
unnamed: C113.2, J115.1, J115.2
unnamed: C114.1, J108.1, J108.2
unnamed: C114.2, J116.1, J116.2
unnamed: C115.1, J109.1, J109.2
unnamed: C115.2, J117.1, J117.2
unnamed: C116.1, J110.1, J110.2
unnamed: C116.2, J118.1, J118.2
unnamed: C117.1, J111.1, J111.2
unnamed: C117.2, J119.1, J119.2
unnamed: C118.1, J112.1, J112.2
unnamed: C118.2, J120.1, J120.2
unnamed: D102.1 (K), J148.1, J148.2
unnamed: D102.2 (A), J140.1, J140.2
unnamed: D103.1 (K), J149.1, J149.2
unnamed: D103.2 (A), J141.1, J141.2
unnamed: D104.1 (RK), D104.2 (GK), D104.3 (BK), J155.1, J155.2
unnamed: D104.4 (BA), J139.1, J139.2
unnamed: D104.5 (GA), J138.1, J138.2
unnamed: D104.6 (RA), J137.1, J137.2
unnamed: J121.1, J121.2, R103.1
unnamed: J122.1, J122.2, R104.1
unnamed: J123.1, J123.2, R105.1
unnamed: J124.1, J124.2, R106.1
unnamed: J125.1, J125.2, R107.1
unnamed: J126.1, J126.2, R108.1
unnamed: J127.1, J127.2, R109.1
unnamed: J128.1, J128.2, R110.1
unnamed: J129.1, J129.2, R103.2
unnamed: J130.1, J130.2, R104.2
unnamed: J131.1, J131.2, R105.2
unnamed: J132.1, J132.2, R106.2
unnamed: J133.1, J133.2, R107.2
unnamed: J134.1, J134.2, R108.2
unnamed: J135.1, J135.2, R109.2
unnamed: J136.1, J136.2, R110.2
unnamed: J142.1, J142.2, R111.1
unnamed: J143.1, J143.2, SW104.2
unnamed: J144.1, J144.2, SW103.1 (A)
unnamed: J145.1, J145.2, RV101.1
unnamed: J146.1, J146.2, LS101.1
unnamed: J147.1, J147.2, RV101.2
unnamed: J150.1, J150.2, R111.2
unnamed: J151.1, J151.2, SW104.1
unnamed: J152.1, J152.2, SW103.2 (B)
unnamed: J153.1, J153.2, RV101.3
unnamed: J154.1, J154.2, LS101.2
unnamed: J156.1, J156.2, T101.5 (S2)
unnamed: J157.1, J157.2, T101.2 (PM)
unnamed: J158.1, J158.2, T101.4 (S1)
unnamed: J159.1, J159.2, J159.3, Q101.3 (C)
unnamed: J160.1, J160.2, J160.3, Q102.3 (C)
unnamed: J161.1, J161.2, J161.3, Q103.3 (C)
unnamed: J162.1, J162.2, J162.3, Q101.2 (B)
unnamed: J163.1, J163.2, J163.3, Q102.2 (B)
unnamed: J164.1, J164.2, J164.3, Q103.2 (B)
unnamed: J165.1, J165.2, J165.3, Q101.1 (E)
unnamed: J166.1, J166.2, J166.3, Q102.1 (E)
unnamed: J167.1, J167.2, J167.3, Q103.1 (E)
unnamed: J168.1, J168.2, T101.1 (PR1)
unnamed: J169.1, J169.2, T101.3 (PR2)
unnamed: J172.1, J172.2, J172.3, J172.4, J172.5, J172.6
unnamed: J173.1, J173.2, J173.3, J173.4, J173.5, J173.6
unnamed: J174.1, J174.2, J174.3, J174.4, J174.5, J174.6
unnamed: J175.1, J175.2, J175.3, J175.4, J175.5, J175.6

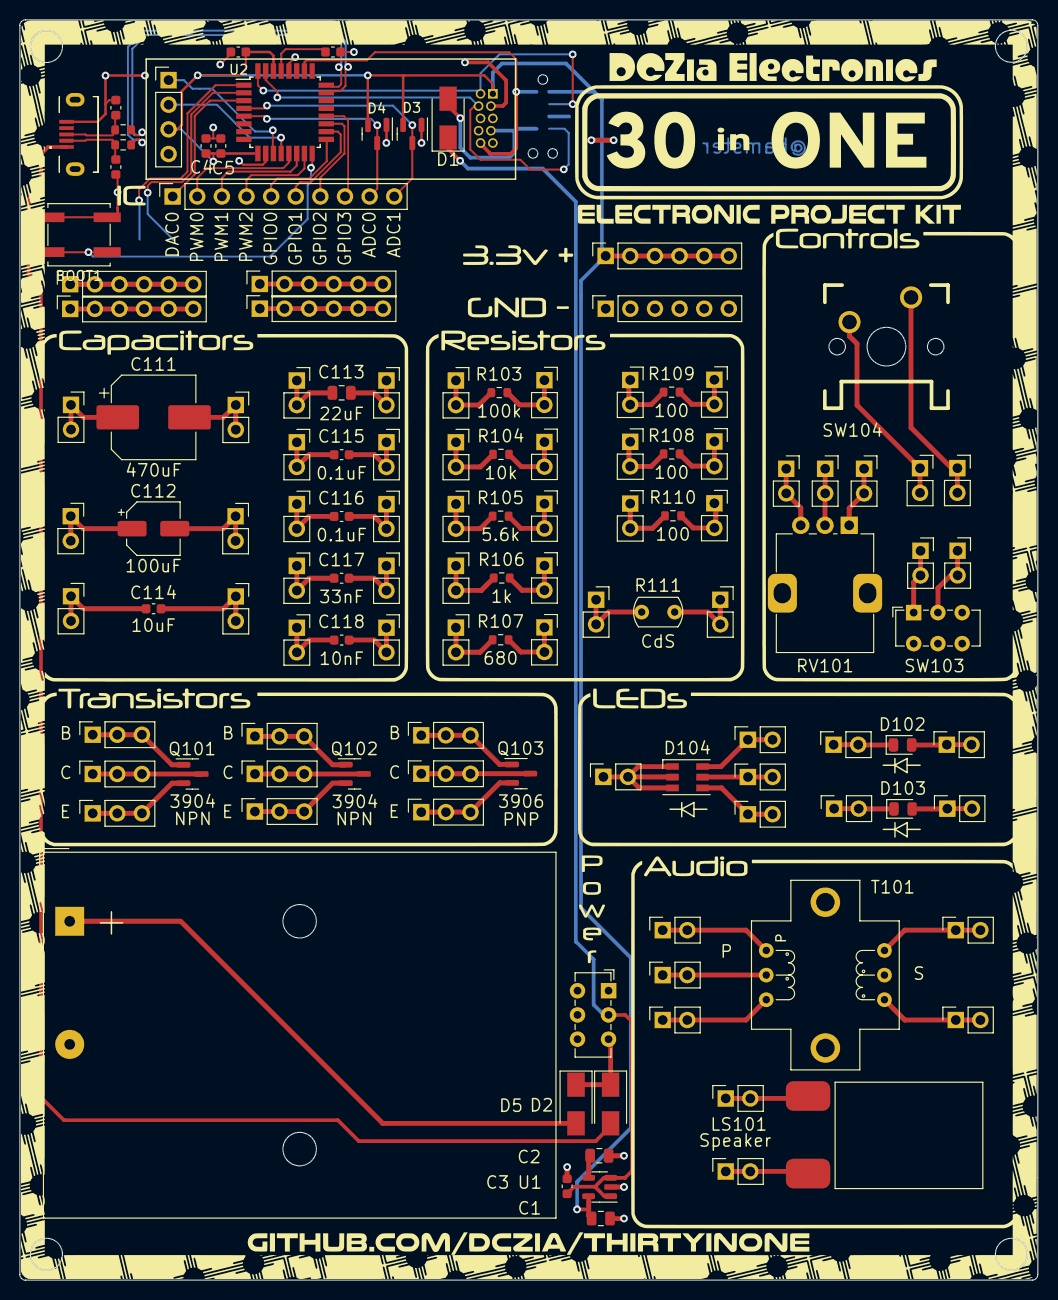
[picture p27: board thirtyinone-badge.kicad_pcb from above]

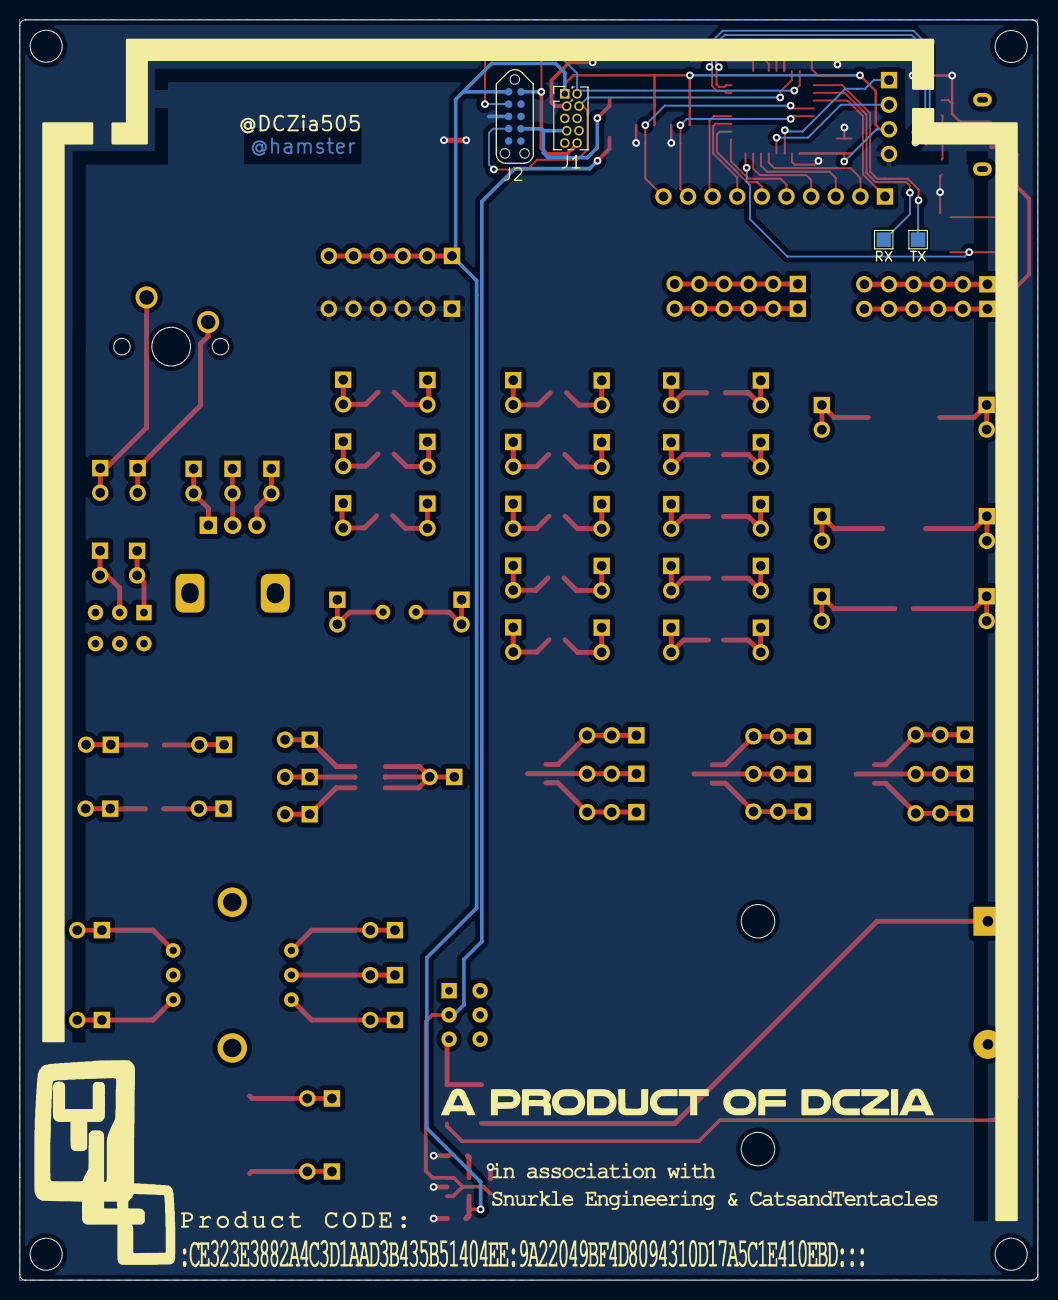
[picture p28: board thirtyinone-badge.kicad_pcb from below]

Board: 2 copper layers, 105.0 x 130.0 mm, 127 parts (4 on the bottom side), 100 nets.

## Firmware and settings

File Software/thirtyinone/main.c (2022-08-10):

#include <atmel_start.h>
#include <stdio.h>
#include "drv_ssd1306.h"
#include "gfx.h"


static struct timer_task TIMER_0_task1;
static uint8_t pwm_compare[3] = { 255, 0, 0 };
static uint8_t pwm_level[3] = { 0 };

/*
 Timer callback
 This gets called every millisecond
 The main app basically sets the point at which the pin flips, effectively changing the duty cycle of the pin.
*/
static void TIMER_0_task1_cb(const struct timer_task *const timer_task){
		
	if(pwm_level[0] >= pwm_compare[0]){
		gpio_set_pin_level(PWM0, false);
	}
	else{
		gpio_set_pin_level(PWM0, true);
	}
	
	if(pwm_level[1] >= pwm_compare[1]){
		gpio_set_pin_level(PWM1, false);
	}
	else{
		gpio_set_pin_level(PWM1, true);
	}
	
	if(pwm_level[2] >= pwm_compare[2]){
		gpio_set_pin_level(PWM2, false);
	}
	else{
		gpio_set_pin_level(PWM2, true);
	}
	
	pwm_level[0]++;
	pwm_level[1]++;
	pwm_level[2]++;
	
}

int main(void){
	
	// Initialize the system
	atmel_start_init();
	
	gpio_set_pin_pull_mode(PB08, GPIO_PULL_DOWN);
	
	// Init the display
	SSD1306_begin(SSD1306_SWITCHCAPVCC, SSD1306_I2C_ADDRESS, false);
	SSD1306_setRotation(ROTATION_0);
	
    // Boot message
    util_gfx_init();
    util_gfx_set_font(FONT_COMPUTER_12PT);
    util_gfx_set_cursor(10, 1);
    util_gfx_print("DCZia", COLOR_WHITE);
    util_gfx_set_font(FONT_MONO55_8PT);
    util_gfx_set_cursor(10, 18);
    util_gfx_print("30 in ONE", COLOR_WHITE);
    util_gfx_draw_dczia(95, 2, COLOR_WHITE);

    // Display the thing
    SSD1306_display();
	
	// Wait for crowd reaction
	delay_ms(1000);
	
	// Setup the ADC inputs
	uint8_t adc1_buffer[2];
	uint8_t adc2_buffer[2];
	int adc1, adc2;
	adc_sync_enable_channel(&ADC_0, 0);
	
	char ADC1[15];
	char ADC2[15];
	
	// Setup the timer to generate the PWM signals
	TIMER_0_task1.interval = 1;
	TIMER_0_task1.cb       = TIMER_0_task1_cb;
	TIMER_0_task1.mode     = TIMER_TASK_REPEAT;

	timer_add_task(&TIMER_0, &TIMER_0_task1);
	timer_start(&TIMER_0);

	// Now loop, forever, forever... FOREVER!
	uint8_t loop = 0;
	
	uint8_t incrementColor = 1, decrementColor = 0, countColor = 0;
	
	while (1) {
		
		// Set GPIO1 output to whatever GPIO0's level is.  GPIO0 has a pull-down enabled.
		gpio_set_pin_level(GPIO1, gpio_get_pin_level(GPIO0));
		
		// Set the PWM duty cycles to fade the RGB colors
		if(++countColor == 255){
			countColor = 0;
			
			pwm_compare[decrementColor] = 0;
			pwm_compare[incrementColor] = 255;
						
			decrementColor++;
			if(decrementColor > 2){
				decrementColor = 0;
			}
			
			incrementColor++;
			if(incrementColor > 2){
				incrementColor = 0;
			}
		}
		
		pwm_compare[decrementColor]--;
		pwm_compare[incrementColor]++;
				
	
		// Only every 10 times - this makes the button press detection more performant without having to redraw the screen each time
		if((loop % 10) == 0){
			
			// Refresh the ADC about every 100ms
			
			adc_sync_set_inputs(&ADC_0,ADC_INPUTCTRL_MUXPOS_PIN2_Val,0x18,0);
			adc_sync_read_channel(&ADC_0, 0, adc1_buffer, 2);
			adc_sync_set_inputs(&ADC_0,ADC_INPUTCTRL_MUXPOS_PIN3_Val,0x18,0);
			adc_sync_read_channel(&ADC_0, 0, adc2_buffer, 2);
			
			adc1 = (adc1_buffer[1] * 256) + adc1_buffer[0] - 30;
			adc2 = (adc2_buffer[1] * 256) + adc2_buffer[0] - 30;
			
			if(adc1 < 0){
				adc1 = 0;
			}
			if(adc2 < 0){
				adc2 = 0;
			}
		
			
			// Update the display about every 100ms
			SSD1306_clearDisplay();
			util_gfx_set_font(FONT_GAMEPLAY_5PT);
			util_gfx_set_cursor(4, 6);
			util_gfx_print("30", COLOR_WHITE);
			util_gfx_set_cursor(5, 12);
			util_gfx_set_font(FONT_VERAMONO_5PT);
			util_gfx_print("in", COLOR_WHITE);
			util_gfx_set_cursor(1, 23);
			util_gfx_set_font(FONT_GAMEPLAY_5PT);
			util_gfx_print("ONE", COLOR_WHITE);
		
			util_gfx_set_font(FONT_MONO55_8PT);
			util_gfx_set_cursor(35, 8);
			snprintf(ADC1, 15, "ADC1: %d.%02dv", ((adc1 * 360) >> 10) / 100, ((adc1 * 360) >> 10) % 100);
			util_gfx_print(ADC1, COLOR_WHITE);
			util_gfx_set_cursor(35, 20);
			snprintf(ADC2, 15, "ADC2: %d.%02dv", ((adc2 * 360) >> 10) / 100, ((adc2 * 360) >> 10) % 100);
			util_gfx_print(ADC2, COLOR_WHITE);
		
			SSD1306_display();
		
		}
		
		delay_ms(5);
		loop++;
		
	}
}

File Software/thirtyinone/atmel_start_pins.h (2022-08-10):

/*
 * Code generated from Atmel Start.
 *
 * This file will be overwritten when reconfiguring your Atmel Start project.
 * Please copy examples or other code you want to keep to a separate file
 * to avoid losing it when reconfiguring.
 */
#ifndef ATMEL_START_PINS_H_INCLUDED
#define ATMEL_START_PINS_H_INCLUDED

#include <hal_gpio.h>

// SAMD21 has 8 pin functions

#define GPIO_PIN_FUNCTION_A 0
#define GPIO_PIN_FUNCTION_B 1
#define GPIO_PIN_FUNCTION_C 2
#define GPIO_PIN_FUNCTION_D 3
#define GPIO_PIN_FUNCTION_E 4
#define GPIO_PIN_FUNCTION_F 5
#define GPIO_PIN_FUNCTION_G 6
#define GPIO_PIN_FUNCTION_H 7

#define PA00 GPIO(GPIO_PORTA, 0)
#define PA01 GPIO(GPIO_PORTA, 1)
#define PA02 GPIO(GPIO_PORTA, 2)
#define PWM0 GPIO(GPIO_PORTA, 4)
#define PWM1 GPIO(GPIO_PORTA, 5)
#define PA08 GPIO(GPIO_PORTA, 8)
#define PA09 GPIO(GPIO_PORTA, 9)
#define PWM2 GPIO(GPIO_PORTA, 10)
#define BOOTLOAD GPIO(GPIO_PORTA, 15)
#define GPIO0 GPIO(GPIO_PORTA, 18)
#define GPIO1 GPIO(GPIO_PORTA, 19)
#define GPIO2 GPIO(GPIO_PORTA, 20)
#define GPIO3 GPIO(GPIO_PORTA, 21)
#define PB08 GPIO(GPIO_PORTB, 8)
#define PB09 GPIO(GPIO_PORTB, 9)

#endif // ATMEL_START_PINS_H_INCLUDED

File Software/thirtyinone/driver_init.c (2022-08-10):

/*
 * Code generated from Atmel Start.
 *
 * This file will be overwritten when reconfiguring your Atmel Start project.
 * Please copy examples or other code you want to keep to a separate file
 * to avoid losing it when reconfiguring.
 */

#include "driver_init.h"
#include <peripheral_clk_config.h>
#include <utils.h>
#include <hal_init.h>
#include <hpl_gclk_base.h>
#include <hpl_pm_base.h>

#include <hpl_adc_base.h>
#include <hpl_rtc_base.h>

struct timer_descriptor TIMER_0;

struct adc_sync_descriptor ADC_0;

struct i2c_m_sync_desc I2C_0;

struct usart_sync_descriptor USART_0;

struct dac_sync_descriptor DAC_0;

void ADC_0_PORT_init(void)
{

	// Disable digital pin circuitry
	gpio_set_pin_direction(PB08, GPIO_DIRECTION_IN);
	gpio_set_pin_level(PB08, false);
	gpio_set_pin_pull_mode(PB08, GPIO_PULL_DOWN);

	//gpio_set_pin_function(PB08, PINMUX_PB08B_ADC_AIN2);
	
	
	// Disable digital pin circuitry
	gpio_set_pin_direction(PB09, GPIO_DIRECTION_IN);
	gpio_set_pin_level(PB09, false);
	gpio_set_pin_pull_mode(PB09, GPIO_PULL_DOWN);

	//gpio_set_pin_function(PB09, PINMUX_PB09B_ADC_AIN3);
}

void ADC_0_CLOCK_init(void)
{
	_pm_enable_bus_clock(PM_BUS_APBC, ADC);
	_gclk_enable_channel(ADC_GCLK_ID, CONF_GCLK_ADC_SRC);
}

void ADC_0_init(void)
{
	ADC_0_CLOCK_init();
	ADC_0_PORT_init();
	adc_sync_init(&ADC_0, ADC, (void *)NULL);
}

void I2C_0_PORT_init(void)
{

	gpio_set_pin_pull_mode(PA08,
	                       // <y> Pull configuration
	                       // <id> pad_pull_config
	                       // <GPIO_PULL_OFF"> Off
	                       // <GPIO_PULL_UP"> Pull-up
	                       // <GPIO_PULL_DOWN"> Pull-down
	                       GPIO_PULL_OFF);

	gpio_set_pin_function(PA08, PINMUX_PA08C_SERCOM0_PAD0);

	gpio_set_pin_pull_mode(PA09,
	                       // <y> Pull configuration
	                       // <id> pad_pull_config
	                       // <GPIO_PULL_OFF"> Off
	                       // <GPIO_PULL_UP"> Pull-up
	                       // <GPIO_PULL_DOWN"> Pull-down
	                       GPIO_PULL_OFF);

	gpio_set_pin_function(PA09, PINMUX_PA09C_SERCOM0_PAD1);
}

void I2C_0_CLOCK_init(void)
{
	_pm_enable_bus_clock(PM_BUS_APBC, SERCOM0);
	_gclk_enable_channel(SERCOM0_GCLK_ID_CORE, CONF_GCLK_SERCOM0_CORE_SRC);
	_gclk_enable_channel(SERCOM0_GCLK_ID_SLOW, CONF_GCLK_SERCOM0_SLOW_SRC);
}

void I2C_0_init(void)
{
	I2C_0_CLOCK_init();
	i2c_m_sync_init(&I2C_0, SERCOM0);
	I2C_0_PORT_init();
}

void USART_0_PORT_init(void)
{

	gpio_set_pin_function(PA00, PINMUX_PA00D_SERCOM1_PAD0);

	gpio_set_pin_function(PA01, PINMUX_PA01D_SERCOM1_PAD1);
}

void USART_0_CLOCK_init(void)
{
	_pm_enable_bus_clock(PM_BUS_APBC, SERCOM1);
	_gclk_enable_channel(SERCOM1_GCLK_ID_CORE, CONF_GCLK_SERCOM1_CORE_SRC);
}

void USART_0_init(void)
{
	USART_0_CLOCK_init();
	usart_sync_init(&USART_0, SERCOM1, (void *)NULL);
	USART_0_PORT_init();
}

/**
 * \brief Timer initialization function
 *
 * Enables Timer peripheral, clocks and initializes Timer driver
 */
static void TIMER_0_init(void)
{
	_pm_enable_bus_clock(PM_BUS_APBA, RTC);
	_gclk_enable_channel(RTC_GCLK_ID, CONF_GCLK_RTC_SRC);
	timer_init(&TIMER_0, RTC, _rtc_get_timer());
}

void DAC_0_PORT_init(void)
{

	// Disable digital pin circuitry
	gpio_set_pin_direction(PA02, GPIO_DIRECTION_OFF);

	gpio_set_pin_function(PA02, PINMUX_PA02B_DAC_VOUT);
}

void DAC_0_CLOCK_init(void)
{

	_pm_enable_bus_clock(PM_BUS_APBC, DAC);
	_gclk_enable_channel(DAC_GCLK_ID, CONF_GCLK_DAC_SRC);
}

void DAC_0_init(void)
{
	DAC_0_CLOCK_init();
	dac_sync_init(&DAC_0, DAC);
	DAC_0_PORT_init();
}

void system_init(void)
{
	init_mcu();

	// GPIO on PA04

	gpio_set_pin_level(PWM0,
	                   // <y> Initial level
	                   // <id> pad_initial_level
	                   // <false"> Low
	                   // <true"> High
	                   false);

	// Set pin direction to output
	gpio_set_pin_direction(PWM0, GPIO_DIRECTION_OUT);

	gpio_set_pin_function(PWM0, GPIO_PIN_FUNCTION_OFF);

	// GPIO on PA05

	gpio_set_pin_level(PWM1,
	                   // <y> Initial level
	                   // <id> pad_initial_level
	                   // <false"> Low
	                   // <true"> High
	                   false);

	// Set pin direction to output
	gpio_set_pin_direction(PWM1, GPIO_DIRECTION_OUT);

	gpio_set_pin_function(PWM1, GPIO_PIN_FUNCTION_OFF);

	// GPIO on PA10

	gpio_set_pin_level(PWM2,
	                   // <y> Initial level
	                   // <id> pad_initial_level
	                   // <false"> Low
	                   // <true"> High
	                   false);

	// Set pin direction to output
	gpio_set_pin_direction(PWM2, GPIO_DIRECTION_OUT);

	gpio_set_pin_function(PWM2, GPIO_PIN_FUNCTION_OFF);

	// GPIO on PA15

	// Set pin direction to input
	gpio_set_pin_direction(BOOTLOAD, GPIO_DIRECTION_IN);

	gpio_set_pin_pull_mode(BOOTLOAD,
	                       // <y> Pull configuration
	                       // <id> pad_pull_config
	                       // <GPIO_PULL_OFF"> Off
	                       // <GPIO_PULL_UP"> Pull-up
	                       // <GPIO_PULL_DOWN"> Pull-down
	                       GPIO_PULL_UP);

	gpio_set_pin_function(BOOTLOAD, GPIO_PIN_FUNCTION_OFF);

	// GPIO on PA18

	// Set pin direction to input
	gpio_set_pin_direction(GPIO0, GPIO_DIRECTION_IN);

	gpio_set_pin_pull_mode(GPIO0,
	                       // <y> Pull configuration
	                       // <id> pad_pull_config
	                       // <GPIO_PULL_OFF"> Off
	                       // <GPIO_PULL_UP"> Pull-up
	                       // <GPIO_PULL_DOWN"> Pull-down
	                       GPIO_PULL_DOWN);

	gpio_set_pin_function(GPIO0, GPIO_PIN_FUNCTION_OFF);

	// GPIO on PA19

	gpio_set_pin_level(GPIO1,
	                   // <y> Initial level
	                   // <id> pad_initial_level
	                   // <false"> Low
	                   // <true"> High
	                   false);

	// Set pin direction to output
	gpio_set_pin_direction(GPIO1, GPIO_DIRECTION_OUT);

	gpio_set_pin_function(GPIO1, GPIO_PIN_FUNCTION_OFF);

	// GPIO on PA20

	gpio_set_pin_level(GPIO2,
	                   // <y> Initial level
	                   // <id> pad_initial_level
	                   // <false"> Low
	                   // <true"> High
	                   false);

	// Set pin direction to output
	gpio_set_pin_direction(GPIO2, GPIO_DIRECTION_OUT);

	gpio_set_pin_function(GPIO2, GPIO_PIN_FUNCTION_OFF);

	// GPIO on PA21

	gpio_set_pin_level(GPIO3,
	                   // <y> Initial level
	                   // <id> pad_initial_level
	                   // <false"> Low
	                   // <true"> High
	                   false);

	// Set pin direction to output
	gpio_set_pin_direction(GPIO3, GPIO_DIRECTION_OUT);

	gpio_set_pin_function(GPIO3, GPIO_PIN_FUNCTION_OFF);

	ADC_0_init();

	I2C_0_init();

	USART_0_init();

	TIMER_0_init();

	DAC_0_init();
}

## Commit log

2022-07-24 Booklet source and PDF
    Source (.pages) file for team use only -- should not be made publicly accessible.
    PDF has corrected wiring diagrams for projects 25 and 26.
2022-08-02 Initial commit of the 1.0 as-built, missing a few items to prevent puzzle spoilage
    [00-Schematics.kicad_sch, 00-Symbols-1.kicad_sch, 00-Symbols-2.kicad_sch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]
2022-08-10 Adding software for the badge Adding corrections page and build instructions card
    [atmel_start_pins.h, driver_examples.c, driver_init.c]
2022-09-11 Updated to hardware version 1.1 to reflect some footprint fixes, and swap to an alternate microcontroller due to parts availability
    [circuits.kicad_sch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]

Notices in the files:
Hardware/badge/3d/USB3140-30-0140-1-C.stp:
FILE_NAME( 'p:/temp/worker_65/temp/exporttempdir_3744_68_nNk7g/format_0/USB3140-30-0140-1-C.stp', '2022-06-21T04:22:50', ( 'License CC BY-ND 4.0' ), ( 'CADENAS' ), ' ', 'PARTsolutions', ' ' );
